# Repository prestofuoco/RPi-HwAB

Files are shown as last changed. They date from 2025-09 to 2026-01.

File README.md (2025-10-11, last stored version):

# raspberry pi 5 hardware acceleration hat+ with xc7a

> **⚠️ work in progress:** this project is currently in the active pcb design and development phase. the hardware is not yet finalized or available. the repository structure, code, and documentation are placeholders for what is planned. stay tuned for updates!

## overview

welcome to the official repository for my raspberry pi 5 hat+ hardware accelerator. this project aims to create a powerful accelerator board featuring a xilinx artix-7 (xc7a) fpga. the goal is to bring high-speed, parallel processing capabilities to the raspberry pi 5, enabling a new generation of projects in fields like real-time signal processing, machine learning, and computer vision.

currently, the focus is on the **pcb design and layout**. the `pcb/` directory contains the most up-to-date work. other sections of this repository, such as `fpga_src` and `examples`, contain planned structures and will be developed once the hardware is stable.

## planned key features

* **xilinx artix-7 fpga:** will utilize the powerful and efficient xc7a series fpga for custom hardware acceleration
* **hat+ compliant:** designed to the latest raspberry pi hat+ specification for seamless integration and configuration
* **high-speed pcie interface:** aims to leverage the raspberry pi 5's pcie capabilities for maximum data throughput
* **on-board peripherals:** the design will include various peripherals which will be noted here
* **open-source design:** the pcb design, verilog/vhdl examples, and host software will be open-source and available in this repository

## hardware and software requirements (provisional)

### hardware

* a raspberry pi 5
* the final version of this xc7a fpga hat+ board
* a reliable power supply for the raspberry pi 5 (5v/5a recommended)

### software (provisional)

* **raspberry pi os:** ubuntu server 20.04+
* **xilinx vivado design suite:** for developing fpga bitstreams
* **kicad:** for viewing and editing the pcb design files

## project status

this project is currently focused on hardware development.

### 1. pcb design

the kicad project files can be found in the `pcb/` directory. this is the primary area of development right now. feedback and contributions for schematics and layout are welcome.

### 2. future steps (post-hardware)

once the pcb is finalized and fabricated, development will shift to:

1. **board bring-up and testing:** verifying all hardware components.
2. **fpga development:** creating example bitstreams (e.g., led blinker, pcie communication).
3. **host-side software:** writing drivers and libraries to communicate with the fpga from the raspberry pi.

## repository structure

```
.
├── bitstreams/       # (planned) pre-compiled fpga bitstream files
├── docs/             # (planned) detailed documentation and datasheets
├── examples/         # (planned) example projects (host-side code)
├── fpga_src/         # (backlog) verilog/vhdl source code for the fpga
│   └── RPi-HwAB-1/   # main vivado project files
│   └── test/         # pinout verification/experimentation
├── pcb/              # (active development) kicad/altium project files
│   └── simulations/  # ltspice simulation files
├── scripts/          # (planned) installation and helper scripts
├── utils/            # (planned) host-side utility programs
└── readme.md         # this file
```

## contact

andre winkel 14 [at] gmail [dot] com

andre [dot] winkel [at] email [dot] ucr [dot] edu

project link: [https://github.com/prestofuoco/rpi-hwab](https://github.com/prestofuoco/rpi-hwab)

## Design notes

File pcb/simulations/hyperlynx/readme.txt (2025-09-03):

*******************************************************************************
** © Copyright 2012 Xilinx, Inc. All rights reserved.
** This file contains confidential and proprietary information of Xilinx, Inc. and 
** is protected under U.S. and international copyright and other intellectual property laws.
*******************************************************************************
**   ____  ____ 
**  /   /\/   / 
** /___/  \  /   Vendor: Xilinx 
** \   \   \/    
**  \   \        readme.txt Version: 2.8
**  /   /        Date Last Modified: 8/28/2017
** /___/   /\    Date Created: 6/28/2012
** \   \  /  \   Associated Filename: artix7_ibis_v2_8.zip
**  \___\/\___\ 
** 
**  Device: Artix-7
**  Revision History: 2.8 Additional Packages added
**                    2.0 Production model release
**                    1.0 Preliminary model release
**
*******************************************************************************
**
**  Disclaimer: 
**
**		This disclaimer is not a license and does not grant any rights to the materials 
**              distributed herewith. Except as otherwise provided in a valid license issued to you 
**              by Xilinx, and to the maximum extent permitted by applicable law: 
**              (1) THESE MATERIALS ARE MADE AVAILABLE "AS IS" AND WITH ALL FAULTS, 
**              AND XILINX HEREBY DISCLAIMS ALL WARRANTIES AND CONDITIONS, EXPRESS, IMPLIED, OR STATUTORY, 
**              INCLUDING BUT NOT LIMITED TO WARRANTIES OF MERCHANTABILITY, NON-INFRINGEMENT, OR 
**              FITNESS FOR ANY PARTICULAR PURPOSE; and (2) Xilinx shall not be liable (whether in contract 
**              or tort, including negligence, or under any other theory of liability) for any loss or damage 
**              of any kind or nature related to, arising under or in connection with these materials, 
**              including for any direct, or any indirect, special, incidental, or consequential loss 
**              or damage (including loss of data, profits, goodwill, or any type of loss or damage suffered 
**              as a result of any action brought by a third party) even if such damage or loss was 
**              reasonably foreseeable or Xilinx had been advised of the possibility of the same.

**  Critical Applications:
**
**		Xilinx products are not designed or intended to be fail-safe, or for use in any application 
**		requiring fail-safe performance, such as life-support or safety devices or systems, 
**		Class III medical devices, nuclear facilities, applications related to the deployment of airbags,
**		or any other applications that could lead to death, personal injury, or severe property or 
**		environmental damage (individually and collectively, "Critical Applications"). Customer assumes 
**		the sole risk and liability of any use of Xilinx products in Critical Applications, subject only 
**		to applicable laws and regulations governing limitations on product liability.

**  THIS COPYRIGHT NOTICE AND DISCLAIMER MUST BE RETAINED AS PART OF THIS FILE AT ALL TIMES.

*******************************************************************************

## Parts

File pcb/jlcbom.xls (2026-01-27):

Comment | topDesignator | bottomDesignator | Footprint | JLCPCB Part #
0.0031% |  |  | Resistor_SMD:R_1206_3216Metric | C154631
2.2K1% |  |  | Resistor_SMD:R_0402_1005Metric | C2076947
4.7uF |  |  | Capacitor_SMD:C_0603_1608Metric | C19666
100K |  |  | Resistor_SMD:R_0402_1005Metric | C481918
INA230AIRGTR |  |  | Package_DFN_QFN:VQFN-16-1EP_3x3mm_P0.5mm_EP1.6x1.6mm | C882784
0.1uF |  |  | Capacitor_SMD:C_0402_1005Metric | C1525
1001% |  |  | Resistor_SMD:R_0402_1005Metric | C844502
LEDGreen |  |  | LED_SMD:LED_0603_1608Metric | C125093
15K1% |  |  | Resistor_SMD:R_0402_1005Metric | C191587
Hirose_FH12-16S |  |  | Connector_FFC-FPC:Hirose_FH12-17S-0.5SH_1x17-1MP_P0.50mm_Horizontal | C596731
10uF |  |  | Capacitor_SMD:C_1206_3216Metric | C13585
1.5uH |  |  | Inductor_SMD:L_Coilcraft_XAL4020-XXX | C3040382
XC7A100T-FGG484 |  |  | library:Xilinx_FGG484 | C410276
10 |  |  | Resistor_SMD:R_0402_1005Metric | C138066
MCP9804T-E/MC |  |  | Package_DFN_QFN:DFN-8-1EP_3x2mm_P0.5mm_EP1.7x1.4mm | C194710
4.7K |  |  | Resistor_SMD:R_0402_1005Metric | C482193
2401% |  |  | Resistor_SMD:R_0402_1005Metric | C843898
MT41K256M16TW-107:PTR |  |  | Package_BGA:Micron_FBGA-96_7.5x13.5mm_Layout9x16_P0.8mm | C253882
1K |  |  | Resistor_SMD:R_0402_1005Metric | C105637
MX25L12835F |  |  | Package_SON:WSON-8-1EP_6x5mm_P1.27mm_EP3.4x4mm | C190862
4.7nF |  |  | Capacitor_SMD:C_0402_1005Metric | C1538
LEDRed |  |  | LED_SMD:LED_0603_1608Metric | C94869
TPSM82903 |  |  | library:TPSM82903SISR | C6290583
120R@100MHz |  |  | Inductor_SMD:L_0603_1608Metric | C85831
22K |  |  | Resistor_SMD:R_0402_1005Metric | C82868
LEDBlue |  |  | LED_SMD:LED_0603_1608Metric | C99290
22uF |  |  | Capacitor_SMD:C_0603_1608Metric | C59461
0.005 |  |  | Resistor_SMD:R_1206_3216Metric | C844909
2.2uF |  |  | Capacitor_SMD:C_0603_1608Metric | C23630
10K1% |  |  | Resistor_SMD:R_0402_1005Metric | C71617
SiT9365AI-2B2-33 |  |  | Oscillator:Oscillator_SMD_SiTime_PQFD-6L_3.2x2.5mm | C831617
3.9K |  |  | Resistor_SMD:R_0402_1005Metric | C131467
330 |  |  | Resistor_SMD:R_0402_1005Metric | C105875
CAT24C256 |  |  | Package_DFN_QFN:DFN-8-1EP_3x2mm_P0.5mm_EP1.7x1.4mm | C233771
GPIO |  |  | Connector_PinSocket_2.54mm:PinSocket_2x20_P2.54mm_Vertical | C2977589

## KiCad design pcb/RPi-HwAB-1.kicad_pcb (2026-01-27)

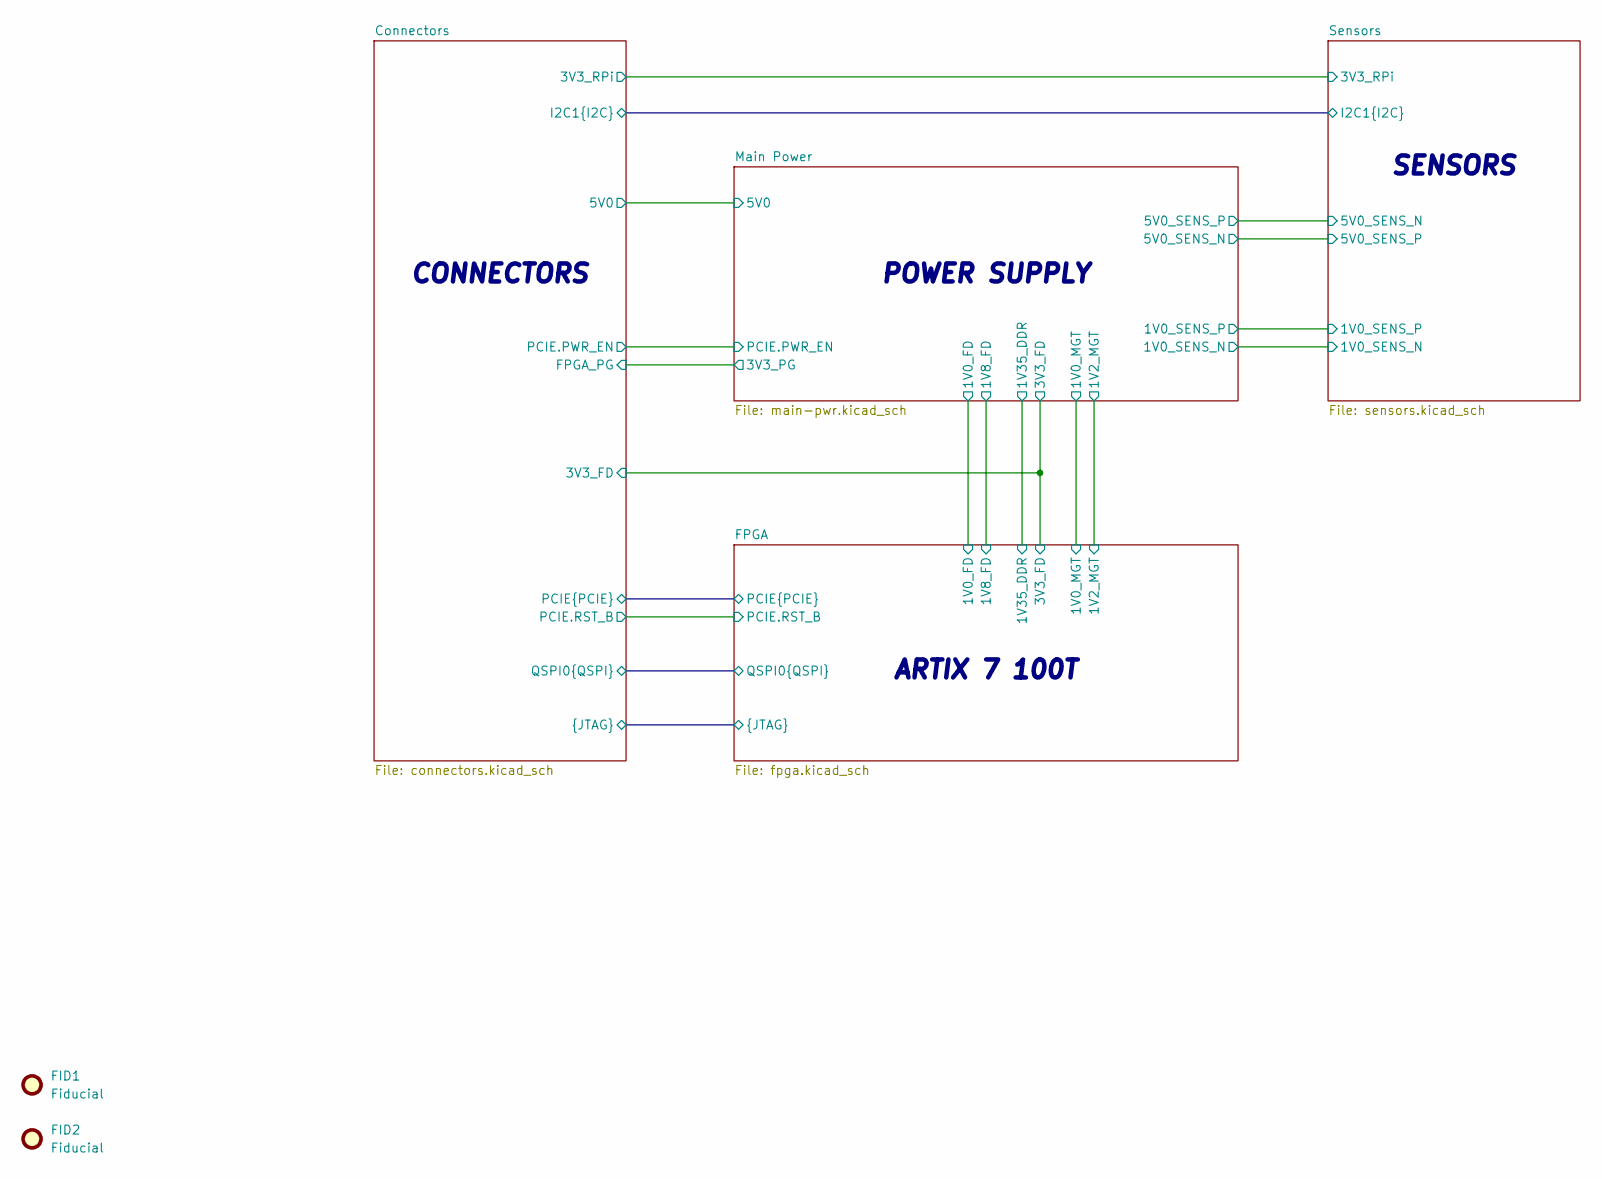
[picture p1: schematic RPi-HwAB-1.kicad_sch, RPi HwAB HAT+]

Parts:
FID1, FID2: Fiducial; Fiducial_1mm_Mask3mm

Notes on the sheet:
ARTIX 7 100T
SENSORS
CONNECTORS
POWER SUPPLY

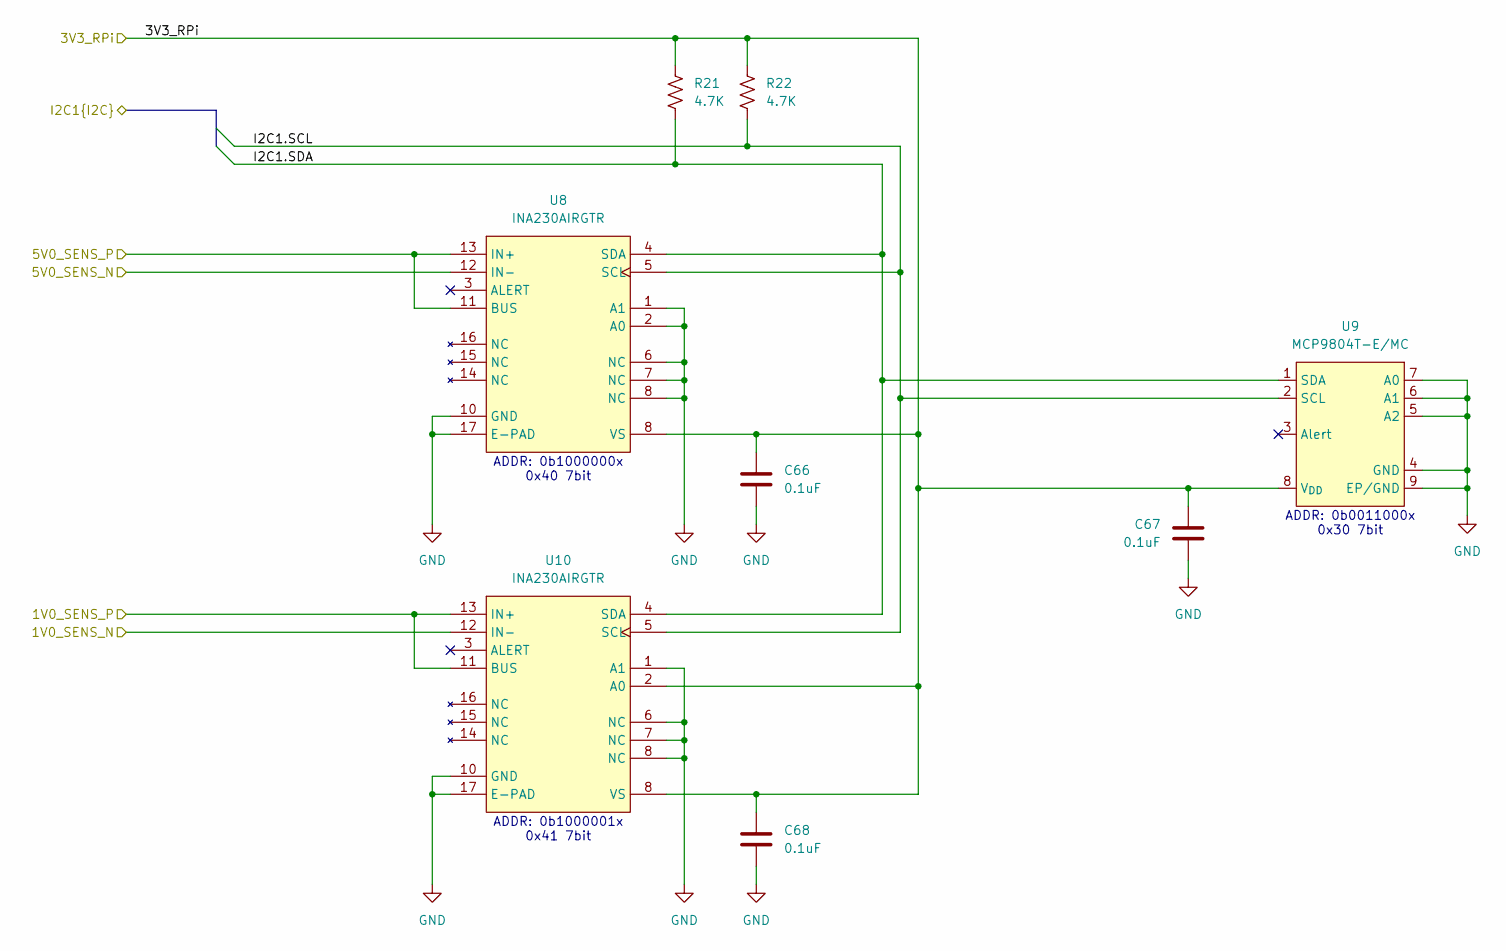
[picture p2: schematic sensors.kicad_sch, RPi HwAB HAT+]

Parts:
C66, C67, C68: 0.1uF; C_0402_1005Metric; Part Description CAP CER 0.1UF 16V X7R 0402
R21, R22: 4.7K; R_0402_1005Metric; Part Description RES 4.7K OHM 1% 1/16W 0402
U8, U10: INA230AIRGTR; VQFN-16-1EP_3x3mm_P0.5mm_EP1.6x1.6mm; Part Description IC CURRENT MONITOR 0.005 16VQFN
U9: MCP9804T-E/MC; DFN-8-1EP_3x2mm_P0.5mm_EP1.7x1.4mm; Part Description SENSOR DIGITAL -40C-125C 8DFN

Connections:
/Connectors/I2C1.SCL: R22.2, U8.5 (SCL), U9.2 (SCL), U10.5 (SCL); also elsewhere on the board
/Connectors/I2C1.SDA: R21.2, U8.4 (SDA), U9.1 (SDA), U10.4 (SDA); also elsewhere on the board
/Main Power/1V0_SENS_N: U10.12 (IN-); also elsewhere on the board
/Main Power/1V0_SENS_P: U10.11 (BUS), U10.13 (IN+); also elsewhere on the board
/Main Power/5V0_SENS_N: U8.11 (BUS), U8.13 (IN+); also elsewhere on the board
/Main Power/5V0_SENS_P: U8.12 (IN-); also elsewhere on the board

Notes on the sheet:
ADDR: 0b0011000x 0x30 7bit
ADDR: 0b1000001x 0x41 7bit
ADDR: 0b1000000x 0x40 7bit

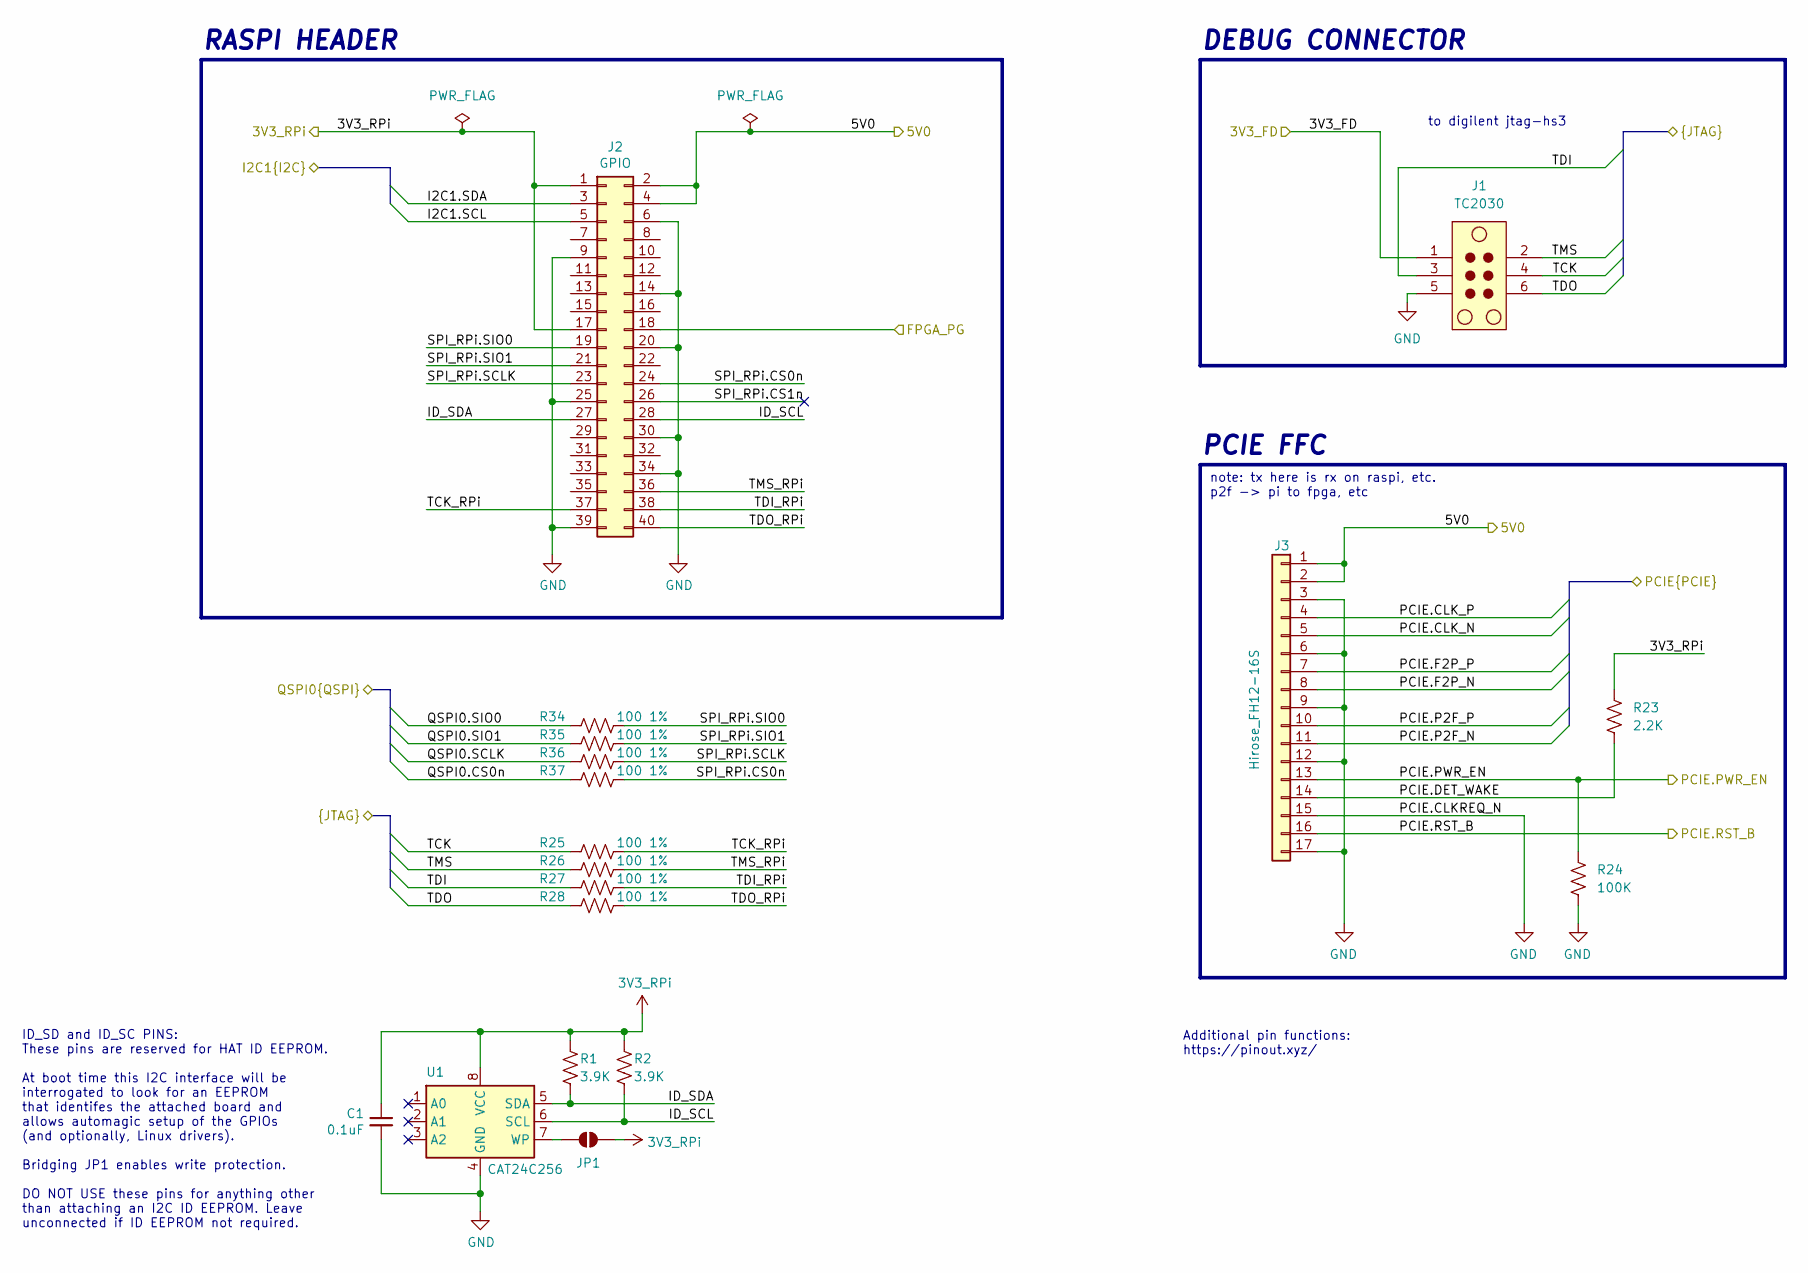
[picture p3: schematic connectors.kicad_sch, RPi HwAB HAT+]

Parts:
C1: 0.1uF; C_0402_1005Metric; Part Description CAP CER 0.1UF 16V X7R 0402
J1: TC2030; Tag-Connect_TC2030-IDC-NL_2x03_P1.27mm_Vertical
J2: GPIO; PinSocket_2x20_P2.54mm_Vertical; Part Description CONN RCPT 40POS 0.1 GOLD PCB
J3: Hirose_FH12-16S; Hirose_FH12-17S-0.5SH_1x17-1MP_P0.50mm_Horizontal; Part Description CONN FFC FPC BOTTOM 16POS 1MM RA
JP1: ID_WP; SolderJumper-2_P1.3mm_Open_Pad1.0x1.5mm
R1, R2: 3.9K; R_0402_1005Metric; Part Description RES 3.9K OHM 1% 1/16W 0402
R23: 2.2K; R_0402_1005Metric; Part Description RES 2.2K OHM 1% 1/16W 0402
R24: 100K; R_0402_1005Metric; Part Description RES 100K OHM 1% 1/16W 0402
R25, R26, R27, R28, R34, R35, R36, R37: 100 1%; R_0402_1005Metric; Part Description RES SMD 100 OHM 1% 1/5W 0402
U1: CAT24C256; DFN-8-1EP_3x2mm_P0.5mm_EP1.7x1.4mm; Part Description IC EEPROM 256KBIT I2C 1MHZ 8UDFN

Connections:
/Connectors/3V3_FD: J1.1; also elsewhere on the board
/Connectors/5V0: J2.2, J2.4, J3.1, J3.2; also elsewhere on the board
/Connectors/I2C1.SCL: J2.5; also elsewhere on the board
/Connectors/I2C1.SDA: J2.3; also elsewhere on the board
/Connectors/ID_SCL: J2.28, R2.2, U1.6 (SCL)
/Connectors/ID_SDA: J2.27, R1.2, U1.5 (SDA)
/Connectors/PCIE.CLK_N: J3.5; also elsewhere on the board
/Connectors/PCIE.CLK_P: J3.4; also elsewhere on the board
/Connectors/PCIE.DET_WAKE: J3.14, R23.2
/Connectors/PCIE.F2P_N: J3.8; also elsewhere on the board
/Connectors/PCIE.F2P_P: J3.7; also elsewhere on the board
/Connectors/PCIE.P2F_N: J3.11; also elsewhere on the board
/Connectors/PCIE.P2F_P: J3.10; also elsewhere on the board
/Connectors/PCIE.PWR_EN: J3.13, R24.2; also elsewhere on the board
/Connectors/PCIE.RST_B: J3.16; also elsewhere on the board
/Connectors/QSPI0.CS0n: R37.1; also elsewhere on the board
/Connectors/QSPI0.SCLK: R36.1; also elsewhere on the board
/Connectors/QSPI0.SIO0: R34.1; also elsewhere on the board
/Connectors/QSPI0.SIO1: R35.1; also elsewhere on the board
/Connectors/SPI_RPi.CS0n: J2.24, R37.2
/Connectors/SPI_RPi.CS1n: J2.26
/Connectors/SPI_RPi.SCLK: J2.23, R36.2
/Connectors/SPI_RPi.SIO0: J2.19, R34.2
/Connectors/SPI_RPi.SIO1: J2.21, R35.2
/Connectors/TCK: J1.4, R25.1; also elsewhere on the board
/Connectors/TCK_RPi: J2.37, R25.2
/Connectors/TDI: J1.3, R27.1; also elsewhere on the board
/Connectors/TDI_RPi: J2.38, R27.2
/Connectors/TDO: J1.6, R28.1; also elsewhere on the board
/Connectors/TDO_RPi: J2.40, R28.2
/Connectors/TMS: J1.2, R26.1; also elsewhere on the board
/Connectors/TMS_RPi: J2.36, R26.2
/Main Power/3V3_PG: J2.18; also elsewhere on the board
unnamed: JP1.1 (A), U1.7 (WP)

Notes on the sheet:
PCIE FFC
note: tx here is rx on raspi, etc. p2f -> pi to fpga, etc
Additional pin functions: https://pinout.xyz/
RASPI HEADER
ID_SD and ID_SC PINS: These pins are reserved for HAT ID EEPROM. At boot time this I2C interface will be interrogated to look for an EEPROM that identifes the attached board and allows automagic setup of the GPIOs (and optionally, Linux drivers). Bridging JP1 enables write protection. DO NOT USE th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
DEBUG CONNECTOR
to digilent jtag-hs3

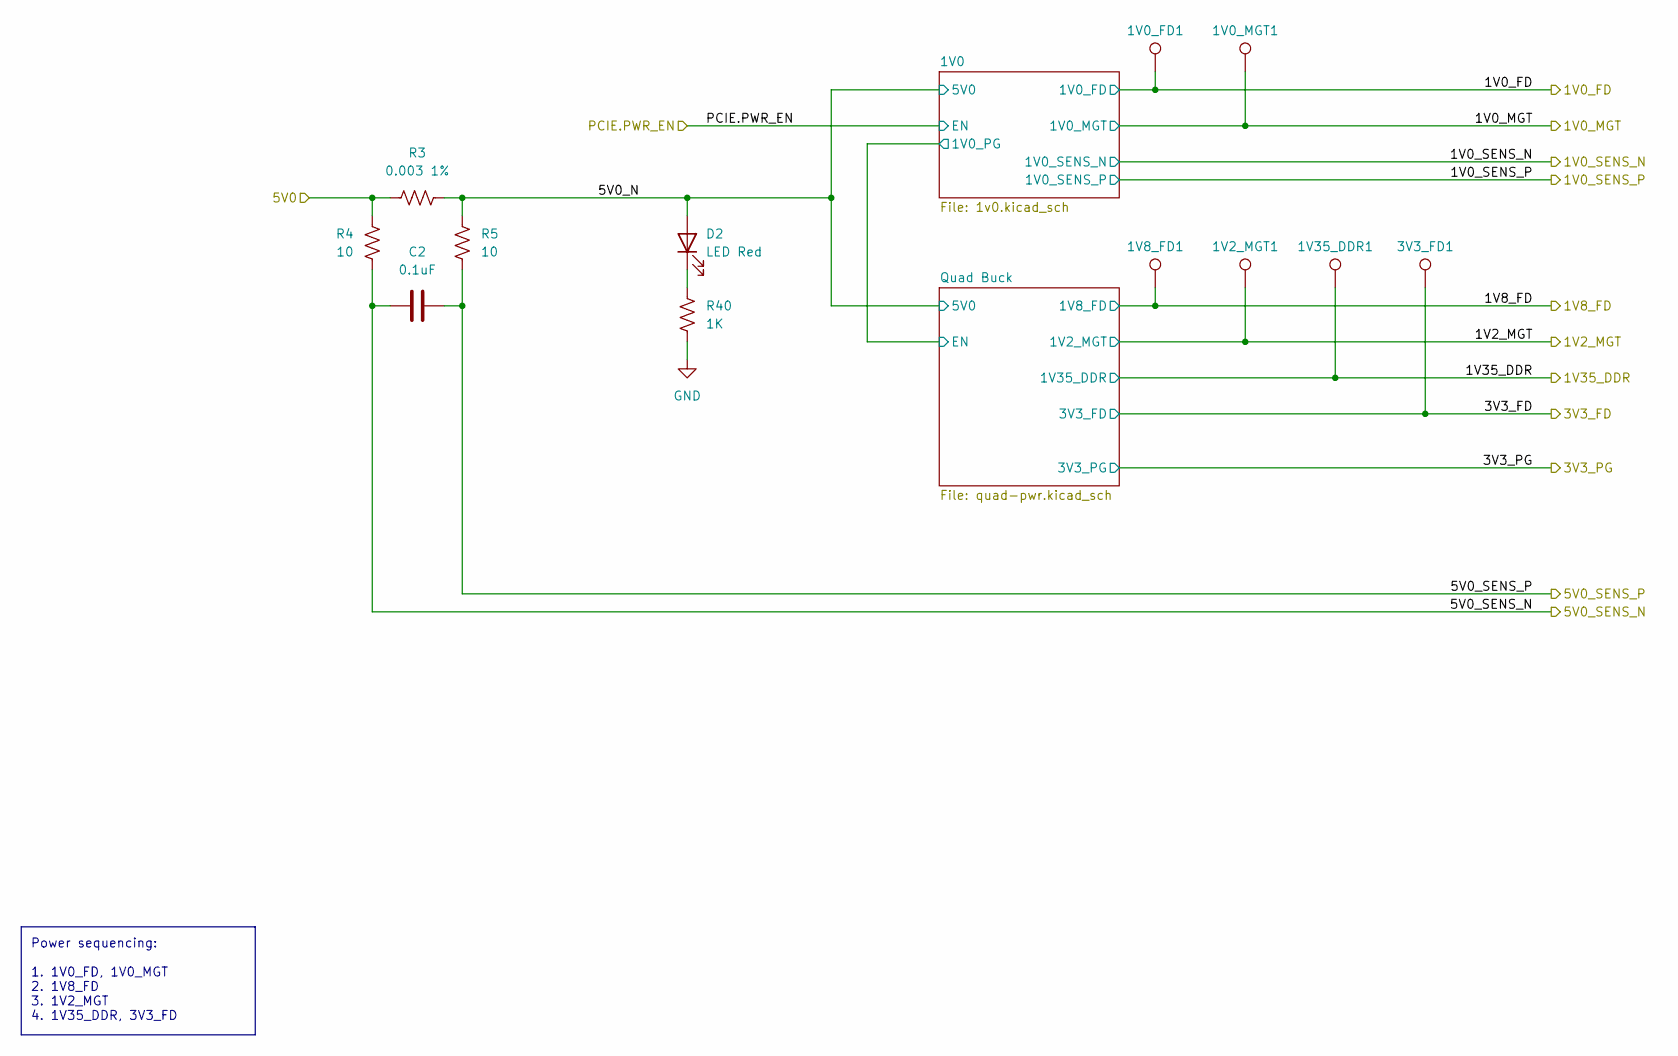
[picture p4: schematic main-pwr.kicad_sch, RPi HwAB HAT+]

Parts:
1V0_FD1, 1V0_MGT1, 1V2_MGT1, 1V8_FD1, 1V35_DDR1, 3V3_FD1: TestPoint; TestPoint_Pad_D1.0mm
C2: 0.1uF; C_0402_1005Metric; Part Description CAP CER 0.1UF 16V X7R 0402
D2: LED Red; LED_0603_1608Metric; Part Description LED RED CLEAR CHIP SMD
R3: 0.003 1%; R_1206_3216Metric; Part Description WSKW0612 .003 1% EA E3
R4, R5: 10; R_0402_1005Metric; Part Description RES 10 OHM 1% 1/16W 0402
R40: 1K; R_0402_1005Metric; Part Description RES 1K OHM 5% 1/16W 0402

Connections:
/Connectors/5V0: R3.1, R4.2; also elsewhere on the board
/Main Power/5V0_N: D2.2 (A), R3.2, R5.2; also elsewhere on the board
/Main Power/5V0_SENS_N: C2.1, R4.1; also elsewhere on the board
/Main Power/5V0_SENS_P: C2.2, R5.1; also elsewhere on the board
unnamed: D2.1 (K), R40.1

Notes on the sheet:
Power sequencing: 1. 1V0_FD, 1V0_MGT 2. 1V8_FD 3. 1V2_MGT 4. 1V35_DDR, 3V3_FD

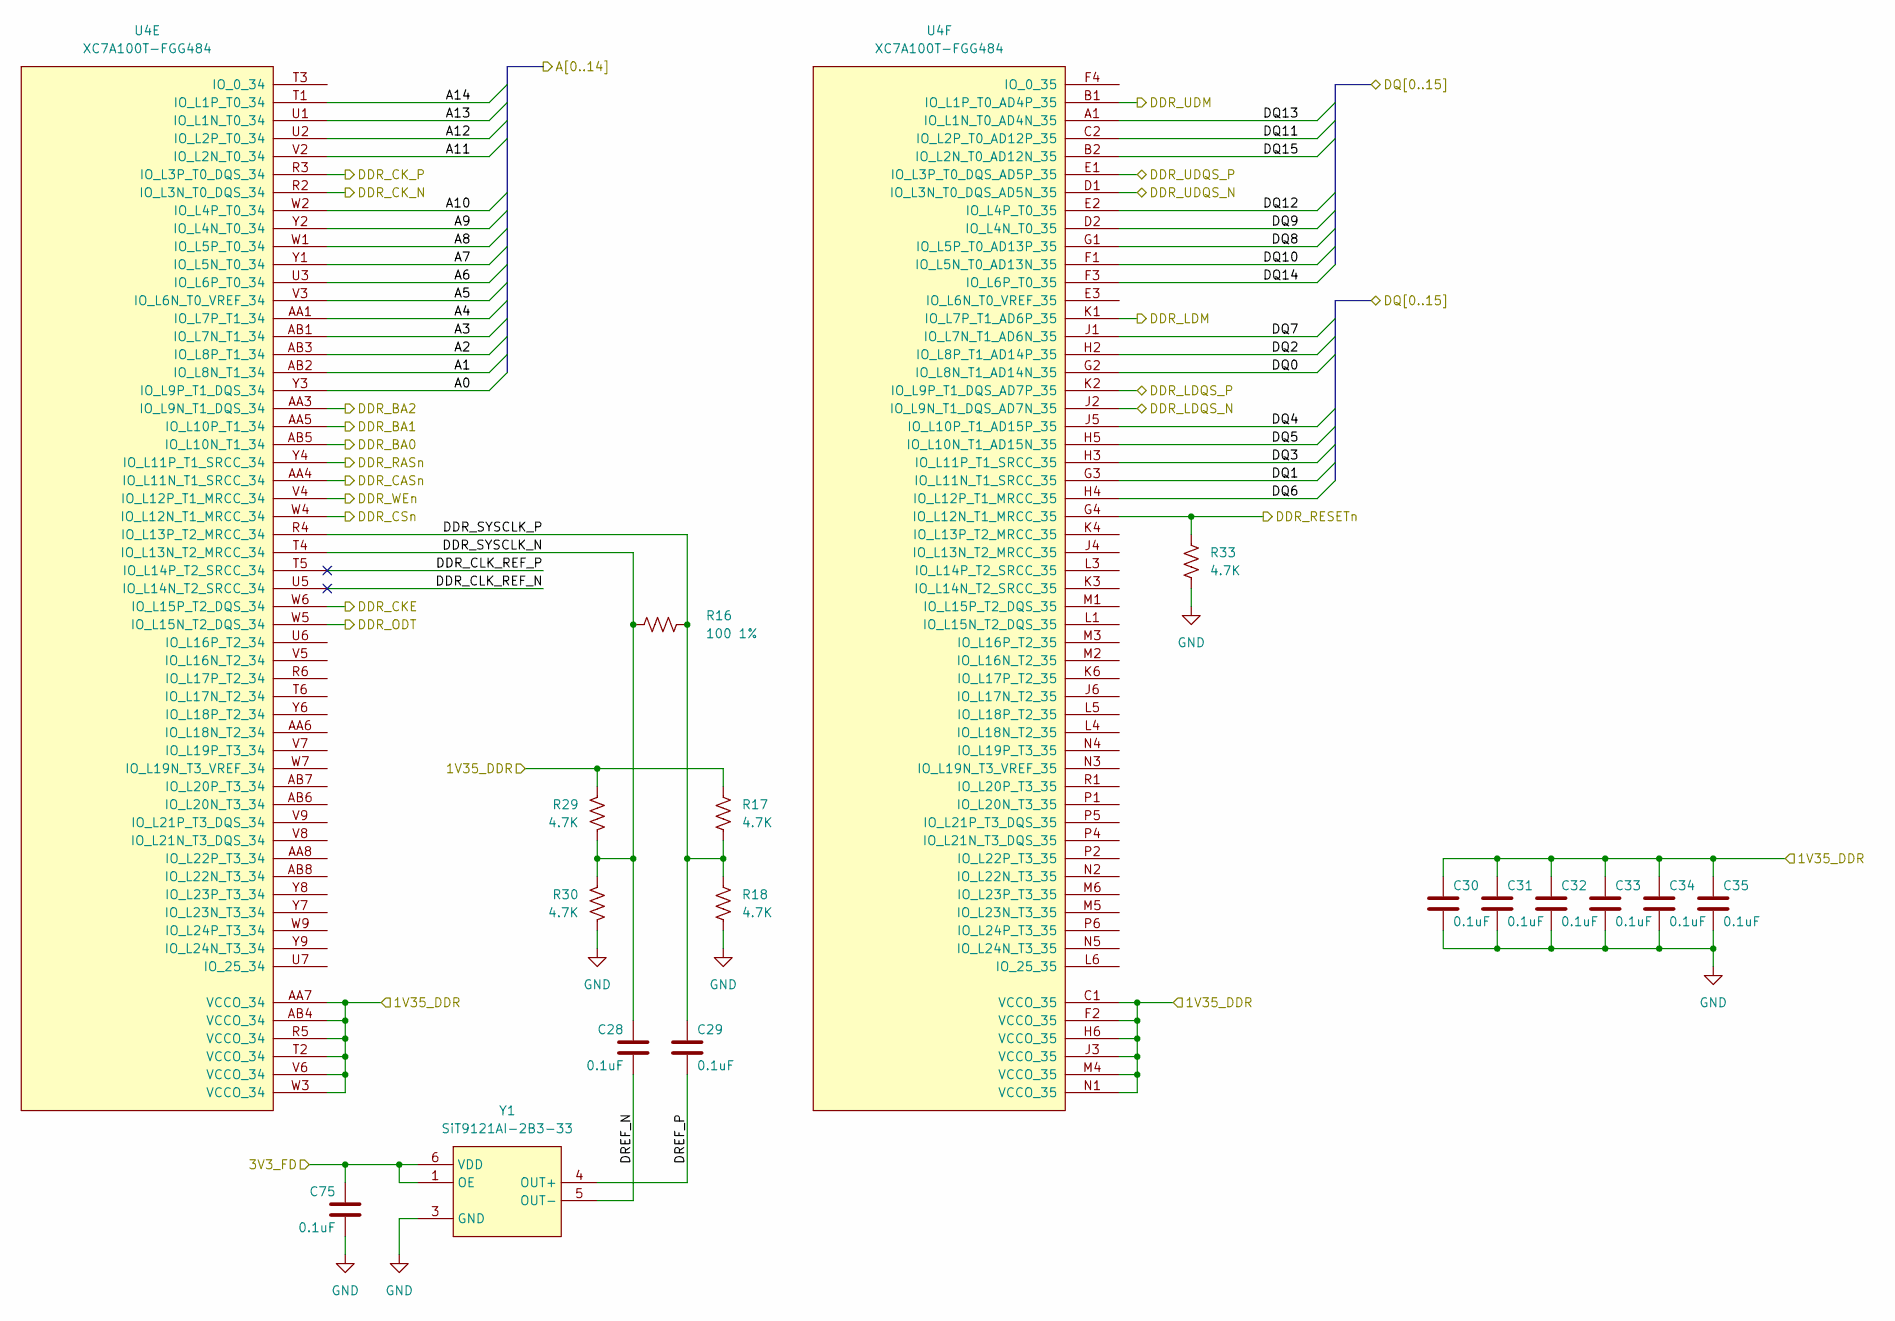
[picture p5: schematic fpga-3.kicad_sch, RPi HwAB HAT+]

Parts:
C28, C29, C30, C31, C32, C33, C34, C35, C75: 0.1uF; C_0402_1005Metric; Part Description CAP CER 0.1UF 16V X7R 0402
R16: 100 1%; R_0402_1005Metric; Part Description RES SMD 100 OHM 1% 1/5W 0402
R17, R18, R29, R30, R33: 4.7K; R_0402_1005Metric; Part Description RES 4.7K OHM 1% 1/16W 0402
U4: XC7A100T-FGG484; Xilinx_FGG484; Part Description IC FPGA 285 I/O 484FBGA
Y1: SiT9121AI-2B3-33; Oscillator_SMD_SiTime_PQFD-6L_3.2x2.5mm; Part Description MEMS OSC XO 156.2500MHZ LVDS SMD

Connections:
/Connectors/3V3_FD: C75.2, Y1.1 (OE), Y1.6 (VDD); also elsewhere on the board
/FPGA/FPGA 34, 35/A0: U4.Y3 (IO_L9P_T1_DQS_34); also elsewhere on the board
/FPGA/FPGA 34, 35/A1: U4.AB2 (IO_L8N_T1_34); also elsewhere on the board
/FPGA/FPGA 34, 35/A2: U4.AB3 (IO_L8P_T1_34); also elsewhere on the board
/FPGA/FPGA 34, 35/A3: U4.AB1 (IO_L7N_T1_34); also elsewhere on the board
/FPGA/FPGA 34, 35/A4: U4.AA1 (IO_L7P_T1_34); also elsewhere on the board
/FPGA/FPGA 34, 35/A5: U4.V3 (IO_L6N_T0_VREF_34); also elsewhere on the board
/FPGA/FPGA 34, 35/A6: U4.U3 (IO_L6P_T0_34); also elsewhere on the board
/FPGA/FPGA 34, 35/A7: U4.Y1 (IO_L5N_T0_34); also elsewhere on the board
/FPGA/FPGA 34, 35/A8: U4.W1 (IO_L5P_T0_34); also elsewhere on the board
/FPGA/FPGA 34, 35/A9: U4.Y2 (IO_L4N_T0_34); also elsewhere on the board
/FPGA/FPGA 34, 35/A10: U4.W2 (IO_L4P_T0_34); also elsewhere on the board
/FPGA/FPGA 34, 35/A11: U4.V2 (IO_L2N_T0_34); also elsewhere on the board
/FPGA/FPGA 34, 35/A12: U4.U2 (IO_L2P_T0_34); also elsewhere on the board
/FPGA/FPGA 34, 35/A13: U4.U1 (IO_L1N_T0_34); also elsewhere on the board
/FPGA/FPGA 34, 35/A14: U4.T1 (IO_L1P_T0_34); also elsewhere on the board
/FPGA/FPGA 34, 35/DDR_BA0: U4.AB5 (IO_L10N_T1_34); also elsewhere on the board
/FPGA/FPGA 34, 35/DDR_BA1: U4.AA5 (IO_L10P_T1_34); also elsewhere on the board
/FPGA/FPGA 34, 35/DDR_BA2: U4.AA3 (IO_L9N_T1_DQS_34); also elsewhere on the board
/FPGA/FPGA 34, 35/DDR_CASn: U4.AA4 (IO_L11N_T1_SRCC_34); also elsewhere on the board
/FPGA/FPGA 34, 35/DDR_CKE: U4.W6 (IO_L15P_T2_DQS_34); also elsewhere on the board
/FPGA/FPGA 34, 35/DDR_CK_N: U4.R2 (IO_L3N_T0_DQS_34); also elsewhere on the board
/FPGA/FPGA 34, 35/DDR_CK_P: U4.R3 (IO_L3P_T0_DQS_34); also elsewhere on the board
/FPGA/FPGA 34, 35/DDR_CLK_REF_N: U4.U5 (IO_L14N_T2_SRCC_34)
/FPGA/FPGA 34, 35/DDR_CLK_REF_P: U4.T5 (IO_L14P_T2_SRCC_34)
/FPGA/FPGA 34, 35/DDR_CSn: U4.W4 (IO_L12N_T1_MRCC_34); also elsewhere on the board
/FPGA/FPGA 34, 35/DDR_LDM: U4.K1 (IO_L7P_T1_AD6P_35); also elsewhere on the board
/FPGA/FPGA 34, 35/DDR_LDQS_N: U4.J2 (IO_L9N_T1_DQS_AD7N_35); also elsewhere on the board
/FPGA/FPGA 34, 35/DDR_LDQS_P: U4.K2 (IO_L9P_T1_DQS_AD7P_35); also elsewhere on the board
/FPGA/FPGA 34, 35/DDR_ODT: U4.W5 (IO_L15N_T2_DQS_34); also elsewhere on the board
/FPGA/FPGA 34, 35/DDR_RASn: U4.Y4 (IO_L11P_T1_SRCC_34); also elsewhere on the board
/FPGA/FPGA 34, 35/DDR_RESETn: R33.1, U4.G4 (IO_L12N_T1_MRCC_35); also elsewhere on the board
/FPGA/FPGA 34, 35/DDR_SYSCLK_N: C28.1, R16.1, R29.2, R30.1, U4.T4 (IO_L13N_T2_MRCC_34)
/FPGA/FPGA 34, 35/DDR_SYSCLK_P: C29.1, R16.2, R17.2, R18.1, U4.R4 (IO_L13P_T2_MRCC_34)
/FPGA/FPGA 34, 35/DDR_UDM: U4.B1 (IO_L1P_T0_AD4P_35); also elsewhere on the board
/FPGA/FPGA 34, 35/DDR_UDQS_N: U4.D1 (IO_L3N_T0_DQS_AD5N_35); also elsewhere on the board
/FPGA/FPGA 34, 35/DDR_UDQS_P: U4.E1 (IO_L3P_T0_DQS_AD5P_35); also elsewhere on the board
/FPGA/FPGA 34, 35/DDR_WEn: U4.V4 (IO_L12P_T1_MRCC_34); also elsewhere on the board
/FPGA/FPGA 34, 35/DQ0: U4.G2 (IO_L8N_T1_AD14N_35); also elsewhere on the board
/FPGA/FPGA 34, 35/DQ1: U4.G3 (IO_L11N_T1_SRCC_35); also elsewhere on the board
/FPGA/FPGA 34, 35/DQ2: U4.H2 (IO_L8P_T1_AD14P_35); also elsewhere on the board
/FPGA/FPGA 34, 35/DQ3: U4.H3 (IO_L11P_T1_SRCC_35); also elsewhere on the board
/FPGA/FPGA 34, 35/DQ4: U4.J5 (IO_L10P_T1_AD15P_35); also elsewhere on the board
/FPGA/FPGA 34, 35/DQ5: U4.H5 (IO_L10N_T1_AD15N_35); also elsewhere on the board
/FPGA/FPGA 34, 35/DQ6: U4.H4 (IO_L12P_T1_MRCC_35); also elsewhere on the board
/FPGA/FPGA 34, 35/DQ7: U4.J1 (IO_L7N_T1_AD6N_35); also elsewhere on the board
/FPGA/FPGA 34, 35/DQ8: U4.G1 (IO_L5P_T0_AD13P_35); also elsewhere on the board
/FPGA/FPGA 34, 35/DQ9: U4.D2 (IO_L4N_T0_35); also elsewhere on the board
/FPGA/FPGA 34, 35/DQ10: U4.F1 (IO_L5N_T0_AD13N_35); also elsewhere on the board
/FPGA/FPGA 34, 35/DQ11: U4.C2 (IO_L2P_T0_AD12P_35); also elsewhere on the board
/FPGA/FPGA 34, 35/DQ12: U4.E2 (IO_L4P_T0_35); also elsewhere on the board
/FPGA/FPGA 34, 35/DQ13: U4.A1 (IO_L1N_T0_AD4N_35); also elsewhere on the board
/FPGA/FPGA 34, 35/DQ14: U4.F3 (IO_L6P_T0_35); also elsewhere on the board
/FPGA/FPGA 34, 35/DQ15: U4.B2 (IO_L2N_T0_AD12N_35); also elsewhere on the board
/FPGA/FPGA 34, 35/DREF_N: C28.2, Y1.5 (OUT-)
/FPGA/FPGA 34, 35/DREF_P: C29.2, Y1.4 (OUT+)
/Main Power/1V35_DDR: C30.2, C31.2, C32.2, C33.2, C34.2, C35.2, R17.1, R29.1, U4.AA7 (VCCO_34), U4.AB4 (VCCO_34), U4.C1 (VCCO_35), U4.F2 (VCCO_35), U4.H6 (VCCO_35), U4.J3 (VCCO_35), U4.M4 (VCCO_35), U4.N1 (VCCO_35), U4.R5 (VCCO_34), U4.T2 (VCCO_34), U4.V6 (VCCO_34), U4.W3 (VCCO_34); also elsewhere on the board

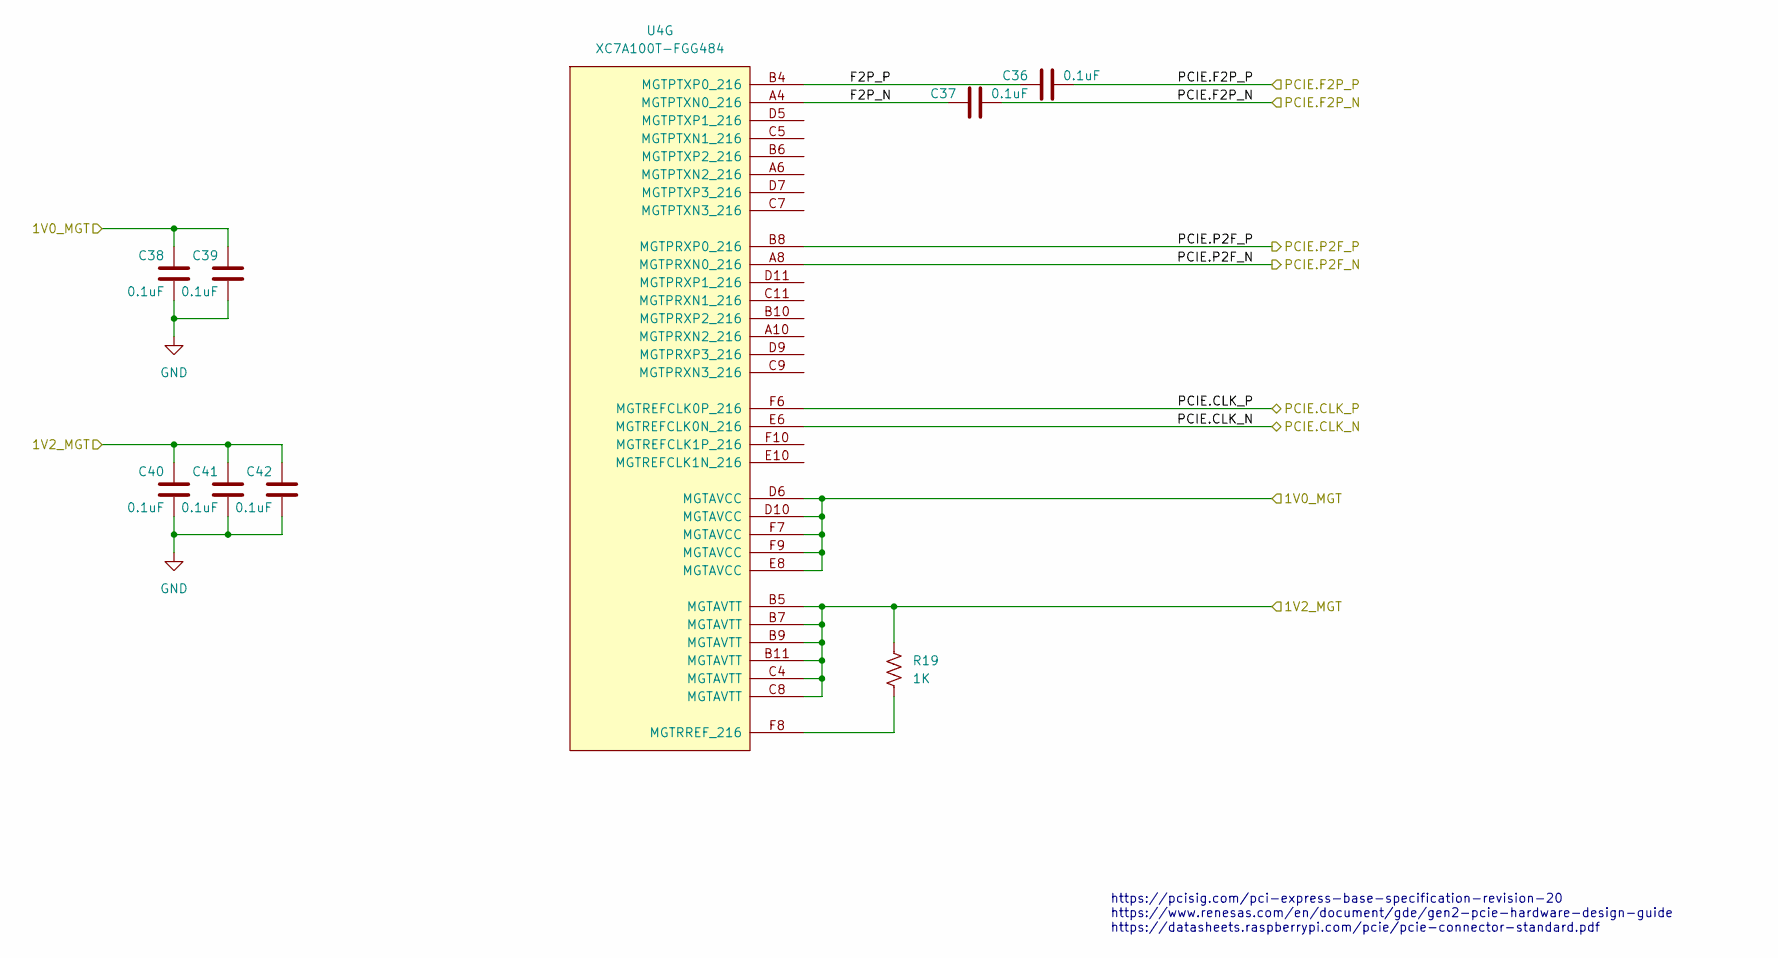
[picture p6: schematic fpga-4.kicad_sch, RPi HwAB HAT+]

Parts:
C36, C37, C38, C39, C40, C41, C42: 0.1uF; C_0402_1005Metric; Part Description CAP CER 0.1UF 16V X7R 0402
R19: 1K; R_0402_1005Metric; Part Description RES 1K OHM 5% 1/16W 0402
U4: XC7A100T-FGG484; Xilinx_FGG484; Part Description IC FPGA 285 I/O 484FBGA

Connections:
/Connectors/PCIE.CLK_N: U4.F6 (MGTREFCLK0P_216); also elsewhere on the board
/Connectors/PCIE.CLK_P: U4.E6 (MGTREFCLK0N_216); also elsewhere on the board
/Connectors/PCIE.F2P_N: C36.2; also elsewhere on the board
/Connectors/PCIE.F2P_P: C37.2; also elsewhere on the board
/Connectors/PCIE.P2F_N: U4.B8 (MGTPRXP0_216); also elsewhere on the board
/Connectors/PCIE.P2F_P: U4.A8 (MGTPRXN0_216); also elsewhere on the board
/FPGA/FPGA 216/F2P_N: C37.1, U4.A4 (MGTPTXN0_216)
/FPGA/FPGA 216/F2P_P: C36.1, U4.B4 (MGTPTXP0_216)
/Main Power/1V0_MGT: C38.2, C39.2, U4.D6 (MGTAVCC), U4.D10 (MGTAVCC), U4.E8 (MGTAVCC), U4.F7 (MGTAVCC), U4.F9 (MGTAVCC); also elsewhere on the board
/Main Power/1V2_MGT: C40.2, C41.2, C42.2, R19.2, U4.B5 (MGTAVTT), U4.B7 (MGTAVTT), U4.B9 (MGTAVTT), U4.B11 (MGTAVTT), U4.C4 (MGTAVTT), U4.C8 (MGTAVTT); also elsewhere on the board
unnamed: R19.1, U4.F8 (MGTRREF_216)

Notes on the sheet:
https://pcisig.com/pci-express-base-specification-revision-20 https://www.renesas.com/en/document/gde/gen2-pcie-hardware-design-guide https://datasheets.raspberrypi.com/pcie/pcie-connector-standard.pdf

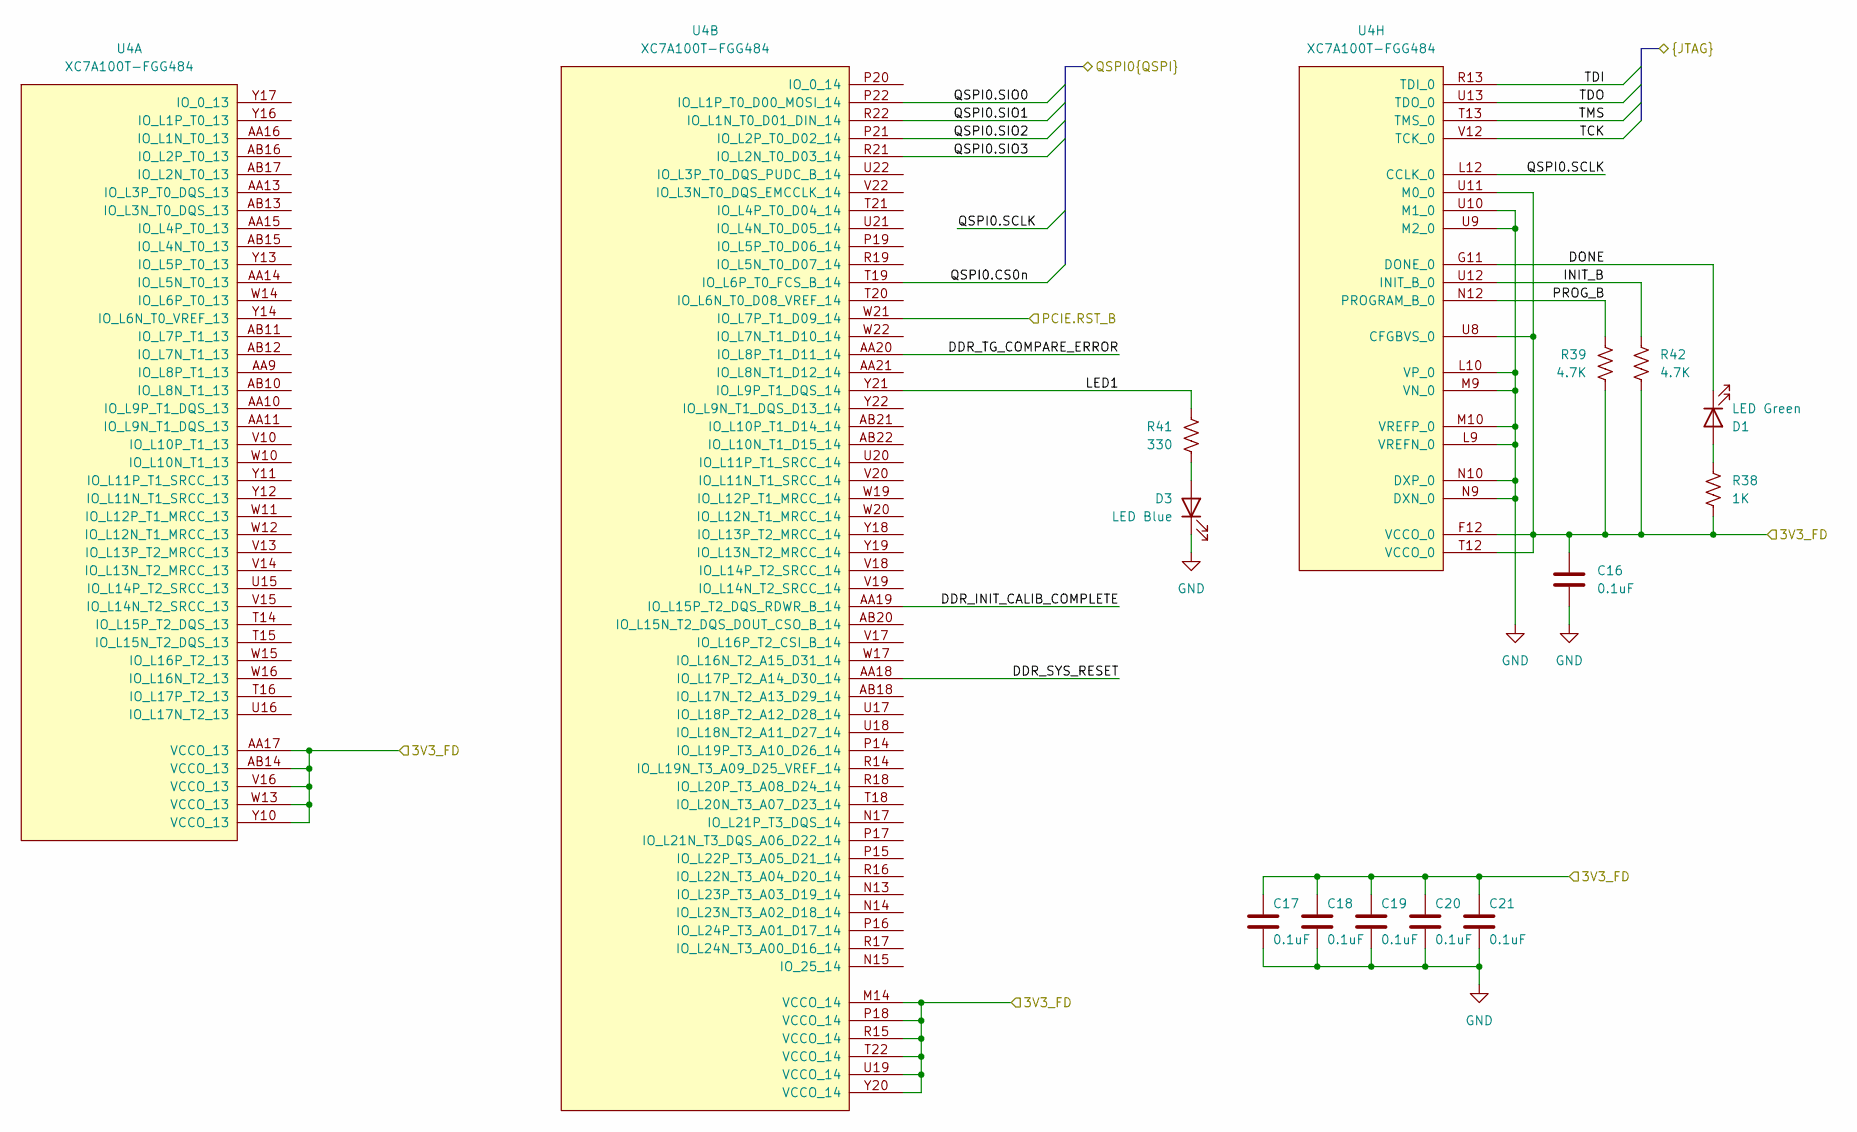
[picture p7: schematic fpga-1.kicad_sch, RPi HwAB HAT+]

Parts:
C16, C17, C18, C19, C20, C21: 0.1uF; C_0402_1005Metric; Part Description CAP CER 0.1UF 16V X7R 0402
D1: LED Green; LED_0603_1608Metric; Part Description LED GREEN CLEAR CHIP SMD
D3: LED Blue; LED_0603_1608Metric; Part Description LED BLUE CLEAR CHIP SMD
R38: 1K; R_0402_1005Metric; Part Description RES 1K OHM 5% 1/16W 0402
R39, R42: 4.7K; R_0402_1005Metric; Part Description RES 4.7K OHM 1% 1/16W 0402
R41: 330; R_0402_1005Metric; Part Description RES 330 OHM 1% 1/16W 0402
U4: XC7A100T-FGG484; Xilinx_FGG484; Part Description IC FPGA 285 I/O 484FBGA

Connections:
/Connectors/3V3_FD: C16.2, C17.2, C18.2, C19.2, C20.2, C21.2, R38.2, R39.2, R42.2, U4.AA17 (VCCO_13), U4.AB14 (VCCO_13), U4.F12 (VCCO_0), U4.M14 (VCCO_14), U4.P18 (VCCO_14), U4.R15 (VCCO_14), U4.T12 (VCCO_0), U4.T22 (VCCO_14), U4.U8 (CFGBVS_0), U4.U11 (M0_0), U4.U19 (VCCO_14), U4.V16 (VCCO_13), U4.W13 (VCCO_13), U4.Y10 (VCCO_13), U4.Y20 (VCCO_14); also elsewhere on the board
/Connectors/PCIE.RST_B: U4.W21 (IO_L7P_T1_D09_14); also elsewhere on the board
/Connectors/QSPI0.CS0n: U4.T19 (IO_L6P_T0_FCS_B_14); also elsewhere on the board
/Connectors/QSPI0.SCLK: U4.L12 (CCLK_0); also elsewhere on the board
/Connectors/QSPI0.SIO0: U4.P22 (IO_L1P_T0_D00_MOSI_14); also elsewhere on the board
/Connectors/QSPI0.SIO1: U4.R22 (IO_L1N_T0_D01_DIN_14); also elsewhere on the board
/Connectors/QSPI0.SIO2: U4.P21 (IO_L2P_T0_D02_14); also elsewhere on the board
/Connectors/QSPI0.SIO3: U4.R21 (IO_L2N_T0_D03_14); also elsewhere on the board
/Connectors/TCK: U4.V12 (TCK_0); also elsewhere on the board
/Connectors/TDI: U4.R13 (TDI_0); also elsewhere on the board
/Connectors/TDO: U4.U13 (TDO_0); also elsewhere on the board
/Connectors/TMS: U4.T13 (TMS_0); also elsewhere on the board
/FPGA/FPGA 0, 13, 14/DDR_INIT_CALIB_COMPLETE: U4.AA19 (IO_L15P_T2_DQS_RDWR_B_14)
/FPGA/FPGA 0, 13, 14/DDR_SYS_RESET: U4.AA18 (IO_L17P_T2_A14_D30_14)
/FPGA/FPGA 0, 13, 14/DDR_TG_COMPARE_ERROR: U4.AA20 (IO_L8P_T1_D11_14)
/FPGA/FPGA 0, 13, 14/DONE: D1.1 (K), U4.G11 (DONE_0)
/FPGA/FPGA 0, 13, 14/INIT_B: R42.1, U4.U12 (INIT_B_0)
/FPGA/FPGA 0, 13, 14/LED1: R41.1, U4.Y21 (IO_L9P_T1_DQS_14)
/FPGA/FPGA 0, 13, 14/PROG_B: R39.1, U4.N12 (PROGRAM_B_0)
unnamed: D1.2 (A), R38.1
unnamed: D3.2 (A), R41.2

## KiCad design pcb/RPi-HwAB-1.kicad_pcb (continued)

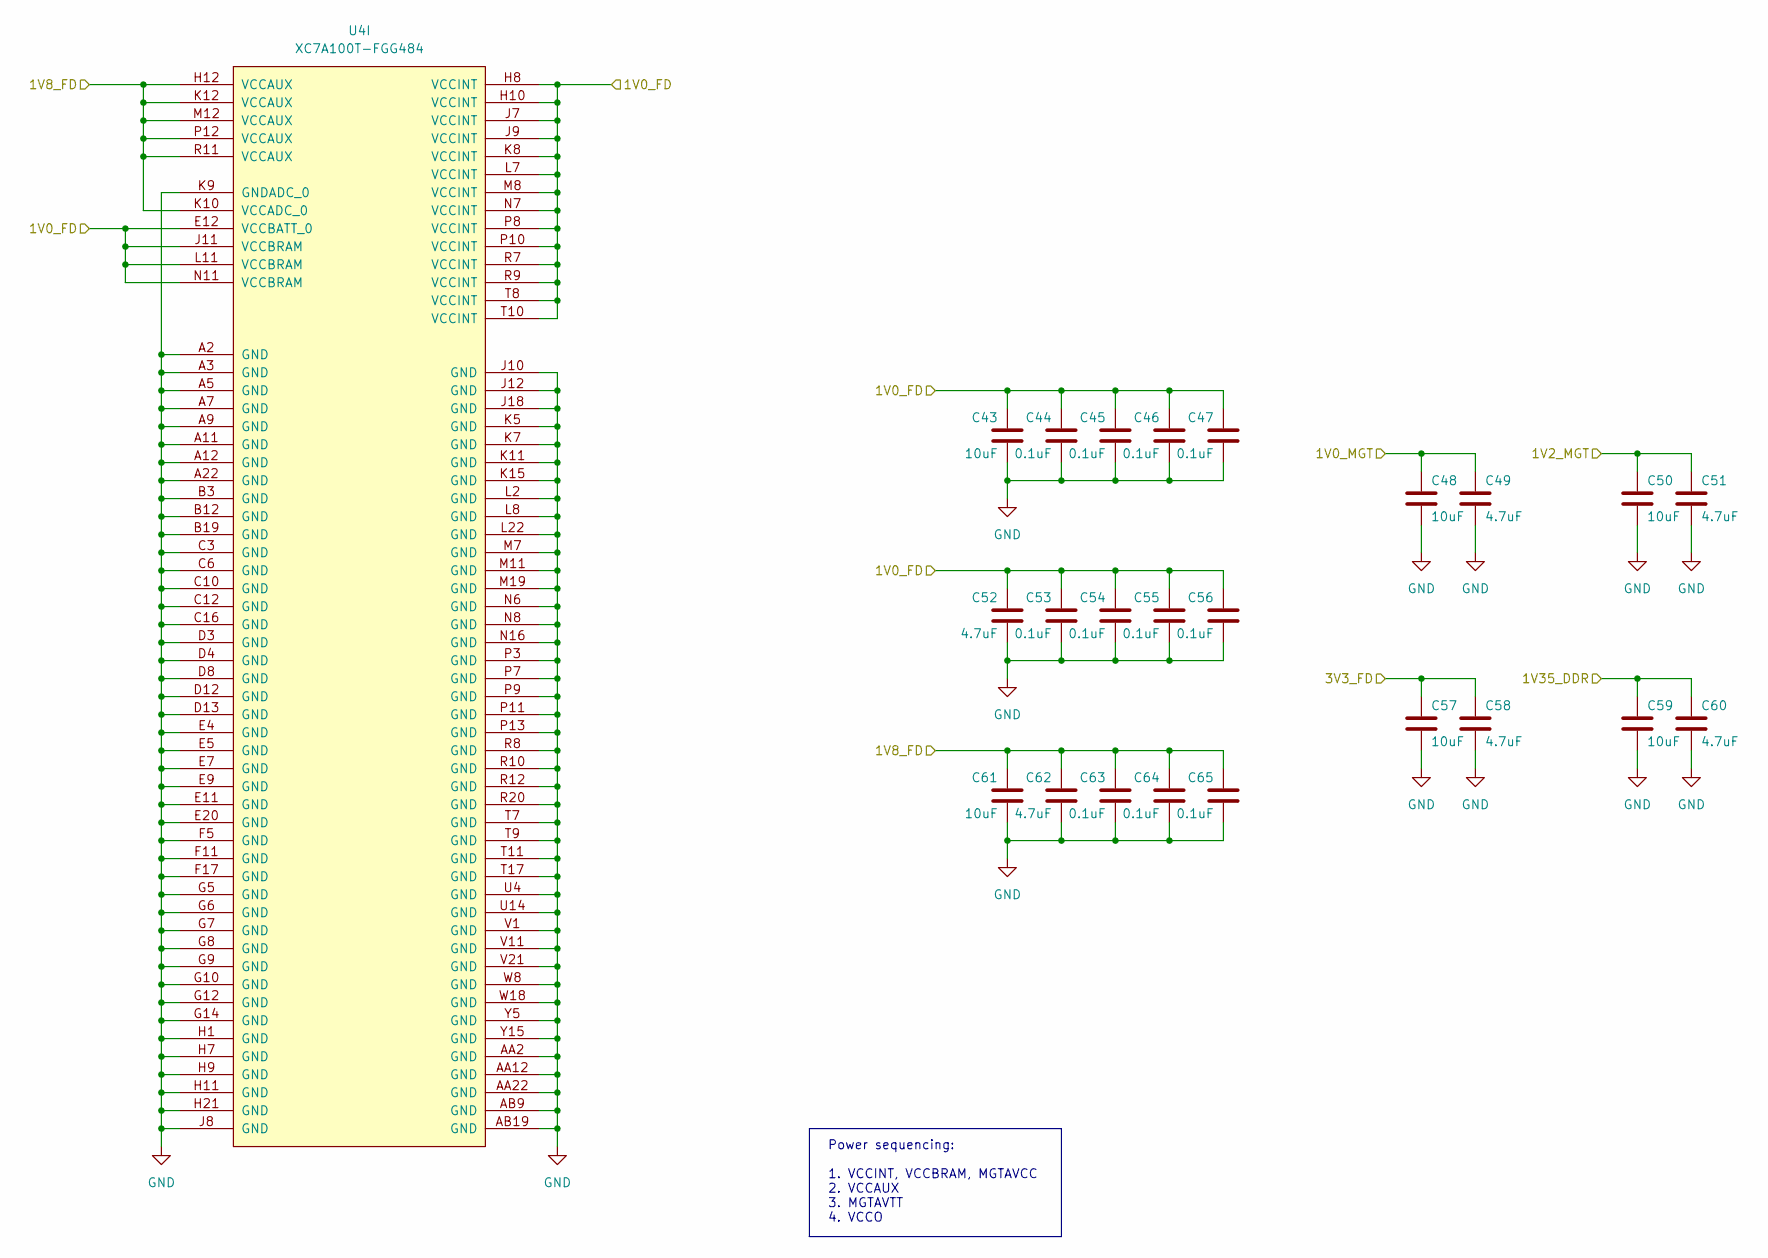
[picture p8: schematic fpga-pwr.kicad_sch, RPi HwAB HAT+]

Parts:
C43, C48, C50, C57, C59, C61: 10uF; C_1206_3216Metric; Part Description CAP TANT 10UF 20% 10V 1206
C44, C45, C46, C47, C53, C54, C55, C56, C63, C64, C65: 0.1uF; C_0402_1005Metric; Part Description CAP CER 0.1UF 16V X7R 0402
C49, C51, C52, C58, C60, C62: 4.7uF; C_0603_1608Metric; Part Description CAP CER 4.7UF 10V X5R 0603
U4: XC7A100T-FGG484; Xilinx_FGG484; Part Description IC FPGA 285 I/O 484FBGA

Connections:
/Connectors/3V3_FD: C57.1, C58.1; also elsewhere on the board
/Main Power/1V0_FD: C43.1, C44.2, C45.2, C46.2, C47.2, C52.1, C53.2, C54.2, C55.2, C56.2, U4.E12 (VCCBATT_0), U4.H8 (VCCINT), U4.H10 (VCCINT), U4.J7 (VCCINT), U4.J9 (VCCINT), U4.J11 (VCCBRAM), U4.K8 (VCCINT), U4.L7 (VCCINT), U4.L11 (VCCBRAM), U4.M8 (VCCINT), U4.N7 (VCCINT), U4.N11 (VCCBRAM), U4.P8 (VCCINT), U4.P10 (VCCINT), U4.R7 (VCCINT), U4.R9 (VCCINT), U4.T8 (VCCINT), U4.T10 (VCCINT); also elsewhere on the board
/Main Power/1V0_MGT: C48.1, C49.1; also elsewhere on the board
/Main Power/1V2_MGT: C50.1, C51.1; also elsewhere on the board
/Main Power/1V8_FD: C61.1, C62.1, C63.2, C64.2, C65.2, U4.H12 (VCCAUX), U4.K10 (VCCADC_0), U4.K12 (VCCAUX), U4.M12 (VCCAUX), U4.P12 (VCCAUX), U4.R11 (VCCAUX); also elsewhere on the board
/Main Power/1V35_DDR: C59.1, C60.1; also elsewhere on the board

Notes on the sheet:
Power sequencing: 1. VCCINT, VCCBRAM, MGTAVCC 2. VCCAUX 3. MGTAVTT 4. VCCO

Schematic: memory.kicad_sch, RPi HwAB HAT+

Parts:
C69, C71, C72, C73, C74: 0.1uF; C_0402_1005Metric; Part Description CAP CER 0.1UF 16V X7R 0402
C70: 4.7uF; C_0603_1608Metric; Part Description CAP CER 4.7UF 10V X5R 0603
R20: 240 1%; R_0402_1005Metric; Part Description RES 240 OHM 1% 1/16W 0402
R31, R32: 2.2K 1%; R_0402_1005Metric; Part Description RES 2.2K OHM 1% 1/16W 0402
U6: MT41K256M16TW-107:P TR; Micron_FBGA-96_7.5x13.5mm_Layout9x16_P0.8mm; Part Description IC DRAM 4GBIT PAR 96FBGA
U7: MX25L12835F; WSON-8-1EP_6x5mm_P1.27mm_EP3.4x4mm; Part Description IC FLASH 128MBIT SPI 8WSON

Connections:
/Connectors/3V3_FD: C74.2, U7.8 (VCC); also elsewhere on the board
/Connectors/QSPI0.CS0n: U7.1 (~CS); also elsewhere on the board
/Connectors/QSPI0.SCLK: U7.6 (SCLK); also elsewhere on the board
/Connectors/QSPI0.SIO0: U7.5 (SI/SIO0); also elsewhere on the board
/Connectors/QSPI0.SIO1: U7.2 (SO/SIO1); also elsewhere on the board
/Connectors/QSPI0.SIO2: U7.3 (~WP/SIO2); also elsewhere on the board
/Connectors/QSPI0.SIO3: U7.7 (~HOLD/SIO3); also elsewhere on the board
/FPGA/FPGA 34, 35/A0: U6.N3 (A0); also elsewhere on the board
/FPGA/FPGA 34, 35/A1: U6.P7 (A1); also elsewhere on the board
/FPGA/FPGA 34, 35/A2: U6.P3 (A2); also elsewhere on the board
/FPGA/FPGA 34, 35/A3: U6.N2 (A3); also elsewhere on the board
/FPGA/FPGA 34, 35/A4: U6.P8 (A4); also elsewhere on the board
/FPGA/FPGA 34, 35/A5: U6.P2 (A5); also elsewhere on the board
/FPGA/FPGA 34, 35/A6: U6.R8 (A6); also elsewhere on the board
/FPGA/FPGA 34, 35/A7: U6.R2 (A7); also elsewhere on the board
/FPGA/FPGA 34, 35/A8: U6.T8 (A8); also elsewhere on the board
/FPGA/FPGA 34, 35/A9: U6.R3 (A9); also elsewhere on the board
/FPGA/FPGA 34, 35/A10: U6.L7 (A10/AP); also elsewhere on the board
/FPGA/FPGA 34, 35/A11: U6.R7 (A11); also elsewhere on the board
/FPGA/FPGA 34, 35/A12: U6.N7 (A12/~BC); also elsewhere on the board
/FPGA/FPGA 34, 35/A13: U6.T3 (A13); also elsewhere on the board
/FPGA/FPGA 34, 35/A14: U6.T7 (A14); also elsewhere on the board
/FPGA/FPGA 34, 35/DDR_BA0: U6.M2 (BA0); also elsewhere on the board
/FPGA/FPGA 34, 35/DDR_BA1: U6.N8 (BA1); also elsewhere on the board
/FPGA/FPGA 34, 35/DDR_BA2: U6.M3 (BA2); also elsewhere on the board
/FPGA/FPGA 34, 35/DDR_CASn: U6.K3 (~CAS); also elsewhere on the board
/FPGA/FPGA 34, 35/DDR_CKE: U6.K9 (CKE); also elsewhere on the board
/FPGA/FPGA 34, 35/DDR_CK_N: U6.K7 (~CK); also elsewhere on the board
/FPGA/FPGA 34, 35/DDR_CK_P: U6.J7 (CK); also elsewhere on the board
/FPGA/FPGA 34, 35/DDR_CSn: U6.L2 (~CS); also elsewhere on the board
/FPGA/FPGA 34, 35/DDR_LDM: U6.E7 (LDM); also elsewhere on the board
/FPGA/FPGA 34, 35/DDR_LDQS_N: U6.G3 (~LDQS); also elsewhere on the board
/FPGA/FPGA 34, 35/DDR_LDQS_P: U6.F3 (LDQS); also elsewhere on the board
/FPGA/FPGA 34, 35/DDR_ODT: U6.K1 (ODT); also elsewhere on the board
/FPGA/FPGA 34, 35/DDR_RASn: U6.J3 (~RAS); also elsewhere on the board
/FPGA/FPGA 34, 35/DDR_RESETn: U6.T2 (~RESET); also elsewhere on the board
/FPGA/FPGA 34, 35/DDR_UDM: U6.D3 (UDM); also elsewhere on the board
/FPGA/FPGA 34, 35/DDR_UDQS_N: U6.B7 (~UDQS); also elsewhere on the board
/FPGA/FPGA 34, 35/DDR_UDQS_P: U6.C7 (UDQS); also elsewhere on the board
/FPGA/FPGA 34, 35/DDR_WEn: U6.L3 (~WE); also elsewhere on the board
/FPGA/FPGA 34, 35/DQ0: U6.E3 (DQ0); also elsewhere on the board
/FPGA/FPGA 34, 35/DQ1: U6.F7 (DQ1); also elsewhere on the board
/FPGA/FPGA 34, 35/DQ2: U6.F2 (DQ2); also elsewhere on the board
/FPGA/FPGA 34, 35/DQ3: U6.F8 (DQ3); also elsewhere on the board
/FPGA/FPGA 34, 35/DQ4: U6.H3 (DQ4); also elsewhere on the board
/FPGA/FPGA 34, 35/DQ5: U6.H8 (DQ5); also elsewhere on the board
/FPGA/FPGA 34, 35/DQ6: U6.G2 (DQ6); also elsewhere on the board
/FPGA/FPGA 34, 35/DQ7: U6.H7 (DQ7); also elsewhere on the board
/FPGA/FPGA 34, 35/DQ8: U6.D7 (DQ8); also elsewhere on the board
/FPGA/FPGA 34, 35/DQ9: U6.C3 (DQ9); also elsewhere on the board
/FPGA/FPGA 34, 35/DQ10: U6.C8 (DQ10); also elsewhere on the board
/FPGA/FPGA 34, 35/DQ11: U6.C2 (DQ11); also elsewhere on the board
/FPGA/FPGA 34, 35/DQ12: U6.A7 (DQ12); also elsewhere on the board
/FPGA/FPGA 34, 35/DQ13: U6.A2 (DQ13); also elsewhere on the board
/FPGA/FPGA 34, 35/DQ14: U6.B8 (DQ14); also elsewhere on the board
/FPGA/FPGA 34, 35/DQ15: U6.A3 (DQ15); also elsewhere on the board
/Main Power/1V35_DDR: C71.2, C72.2, C73.2, R20.2, R31.1, U6.A1 (V_{DDQ}), U6.A8 (V_{DDQ}), U6.B2 (V_{DD}), U6.C1 (V_{DDQ}), U6.C9 (V_{DDQ}), U6.D2 (V_{DDQ}), U6.D9 (V_{DD}), U6.E9 (V_{DDQ}), U6.F1 (V_{DDQ}), U6.G7 (V_{DD}), U6.H2 (V_{DDQ}), U6.H9 (V_{DDQ}), U6.K2 (V_{DD}), U6.K8 (V_{DD}), U6.N1 (V_{DD}), U6.N9 (V_{DD}), U6.R1 (V_{DD}), U6.R9 (V_{DD}); also elsewhere on the board
unnamed: C69.2, C70.1, R31.2, R32.1, U6.H1 (V_{REFDQ}), U6.M8 (V_{REFCA})
unnamed: R20.1, U6.L8 (ZQ)

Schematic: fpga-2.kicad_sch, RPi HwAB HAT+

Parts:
C22, C23, C24, C25, C26, C27: 0.1uF; C_0402_1005Metric; Part Description CAP CER 0.1UF 16V X7R 0402
U4: XC7A100T-FGG484; Xilinx_FGG484; Part Description IC FPGA 285 I/O 484FBGA

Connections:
/Connectors/3V3_FD: C22.2, C23.2, C24.2, C25.2, C26.2, C27.2, U4.A17 (VCCO_16), U4.B14 (VCCO_16), U4.C21 (VCCO_16), U4.D18 (VCCO_16), U4.E15 (VCCO_16), U4.F22 (VCCO_16), U4.G19 (VCCO_15), U4.H16 (VCCO_15), U4.J13 (VCCO_15), U4.K20 (VCCO_15), U4.L17 (VCCO_15), U4.N21 (VCCO_15); also elsewhere on the board

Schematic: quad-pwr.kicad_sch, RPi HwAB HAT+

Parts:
C7, C8, C9, C10, C11: 2.2uF; C_0603_1608Metric; Part Description CAP CER 2.2UF 25V X5R 0603
C12, C13, C14, C15: 22uF; C_0603_1608Metric; Part Description CAP CER 22UF 10V X5R 0603
L1, L2, L3, L4: 1.5uH; L_Coilcraft_XAL4020-XXX; Part Description FIXED IND 1.5UH 7.5A 23.6MOHM SM
R12, R13, R14, R15: 22K; R_0402_1005Metric; Part Description RES 22K OHM 1% 1/16W 0402
U3: MAX20029; WQFN-28-1EP_4x4mm_P0.4mm_EP2.7x2.7mm; Part Description IC REG BUCK ADJ 1.5A QUAD 28TQFN

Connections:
/Connectors/3V3_FD: C13.1, L3.2, U3.14 (OUTS3); also elsewhere on the board
/Main Power/1V0/1V0_PG: U3.1 (EN1); also elsewhere on the board
/Main Power/1V2_MGT: C12.1, L4.2, U3.22 (OUTS4); also elsewhere on the board
/Main Power/1V8_FD: C15.1, L1.2, U3.28 (OUTS1); also elsewhere on the board
/Main Power/1V35_DDR: C14.1, L2.2, U3.8 (OUTS2); also elsewhere on the board
/Main Power/3V3_PG: R13.1, U3.12 (PG3); also elsewhere on the board
/Main Power/5V0_N: C7.1, C8.1, C9.1, C10.1, C11.1, R12.2, R13.2, R14.2, R15.2, U3.2 (PV1), U3.7 (PV2), U3.15 (PV3), U3.20 (PV4), U3.26 (VA); also elsewhere on the board
/Main Power/Quad Buck/1V2_PG: R12.1, U3.9 (EN2), U3.13 (EN3), U3.23 (PG4)
/Main Power/Quad Buck/1V8_PG: R15.1, U3.21 (EN4), U3.27 (PG1)
/Main Power/Quad Buck/1V35_PG: R14.1, U3.10 (PG2)
/Main Power/Quad Buck/LX1: L1.1, U3.3 (LX1)
/Main Power/Quad Buck/LX2: L2.1, U3.6 (LX2)
/Main Power/Quad Buck/LX3: L3.1, U3.16 (LX3)
/Main Power/Quad Buck/LX4: L4.1, U3.19 (LX4)

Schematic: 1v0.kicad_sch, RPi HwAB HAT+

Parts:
C3: 22uF; C_0603_1608Metric; Part Description CAP CER 22UF 10V X5R 0603
C4: 0.1uF; C_0402_1005Metric; Part Description CAP CER 0.1UF 16V X7R 0402
C5: 10uF; C_1206_3216Metric; Part Description CAP TANT 10UF 20% 10V 1206
C6: 4.7nF; C_0402_1005Metric; Part Description CAP CER 0402 4.7NF 50V X7R 5%
FB1: 120R @ 100MHz; L_0603_1608Metric; Part Description FERRITE BEAD 120 OHM 0603 1LN
R6: 0.005; R_1206_3216Metric; Part Description RES 0.005 OHM 1% 1W 1206
R7: 10K 1%; R_0402_1005Metric; Part Description RES 10K OHM 1% 1/16W 0402
R8, R9: 10; R_0402_1005Metric; Part Description RES 10 OHM 1% 1/16W 0402
R10: 15K 1%; R_0402_1005Metric; Part Description RES 15K OHM 1% 1/16W 0402
R11: 22K; R_0402_1005Metric; Part Description RES 22K OHM 1% 1/16W 0402
U2: TPSM82903; TPSM82903SISR; Part Description 3-V TO 17-V, 3-A, HIGH-EFFICIENC

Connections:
/Connectors/PCIE.PWR_EN: U2.3 (EN); also elsewhere on the board
/Main Power/1V0/1V0_FB: R7.2, R10.1, U2.7 (FB/VSET)
/Main Power/1V0/1V0_P: C3.1, R6.2, R7.1, R8.2, U2.9 (VOUT), U2.10 (VOUT)
/Main Power/1V0/1V0_PG: R11.1, U2.6 (PG); also elsewhere on the board
/Main Power/1V0_FD: FB1.1, R6.1, R9.2; also elsewhere on the board
/Main Power/1V0_MGT: FB1.2; also elsewhere on the board
/Main Power/1V0_SENS_N: C4.1, R8.1; also elsewhere on the board
/Main Power/1V0_SENS_P: C4.2, R9.1; also elsewhere on the board
/Main Power/5V0_N: C5.1, R11.2, U2.1 (VIN), U2.2 (VIN), U2.4 (MODE); also elsewhere on the board
unnamed: C6.1, U2.5 (SS/TR)

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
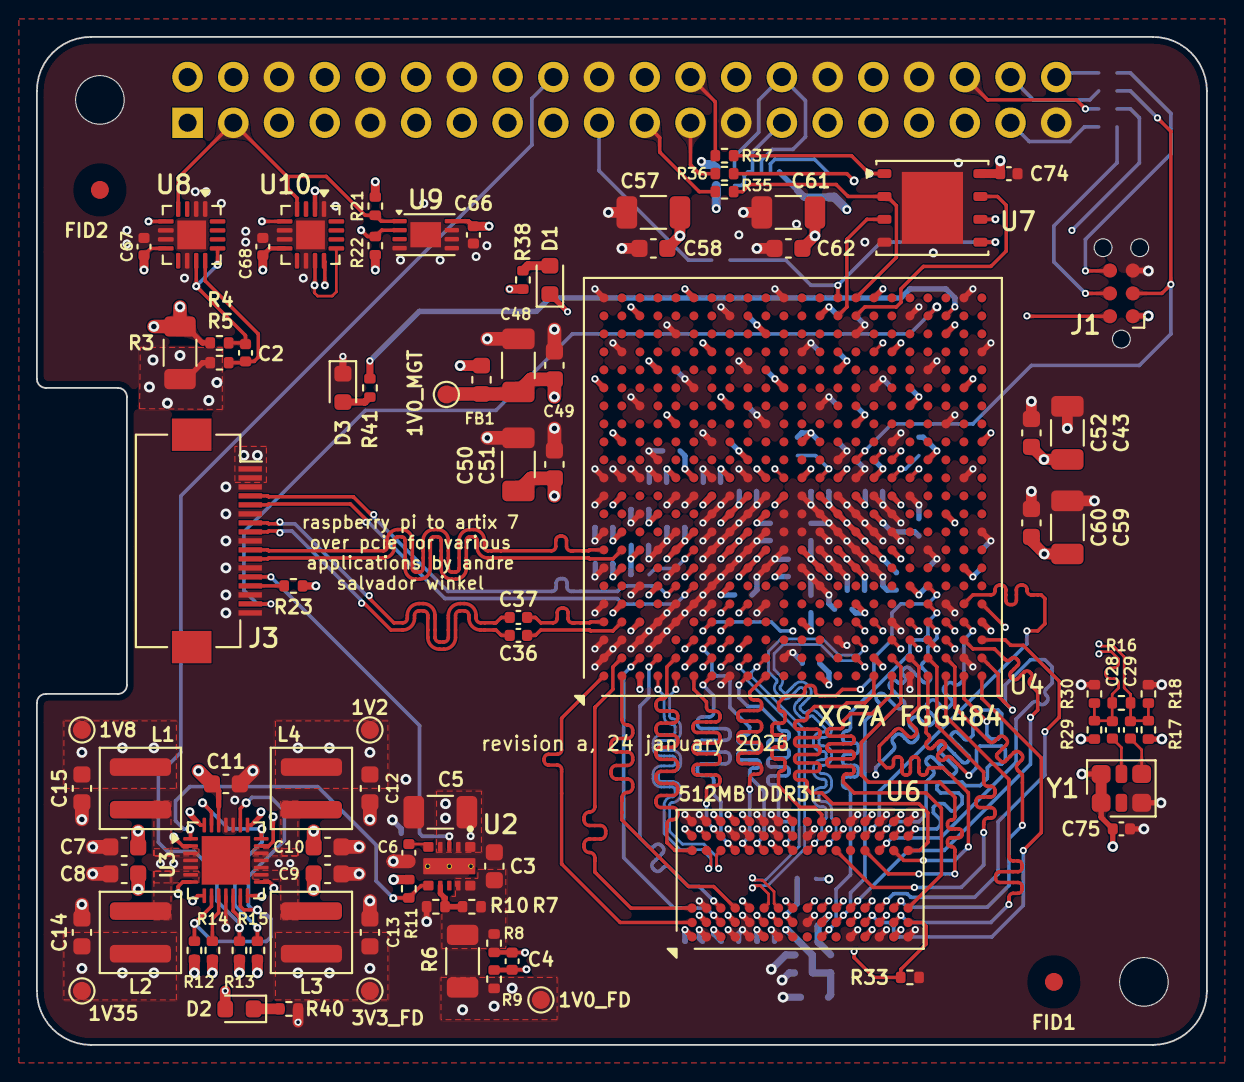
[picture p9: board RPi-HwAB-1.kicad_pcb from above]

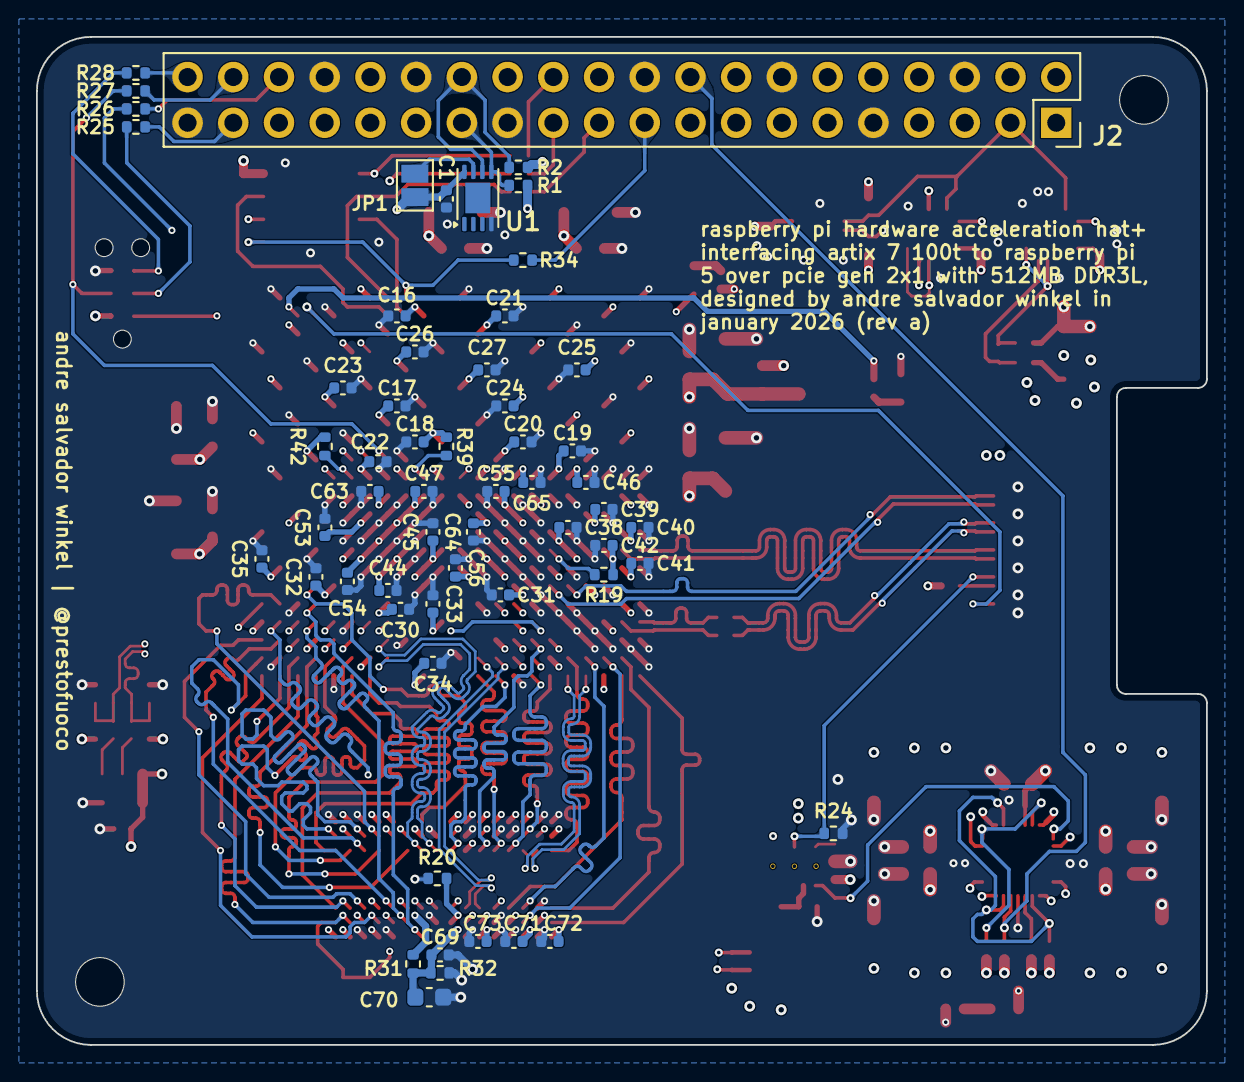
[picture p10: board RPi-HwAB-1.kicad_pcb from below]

Board: 8 copper layers, 65.0 x 56.0 mm, 149 parts (57 on the bottom side), 123 nets.

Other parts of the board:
1V0_FD, 1V0_MGT, 1V2, 1V8, 1V35, 3V3_FD: TestPoint; TestPoint_Pad_D1.0mm
MH1, MH4: MountingHole_2.7mm_M2.5

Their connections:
/Connectors/3V3_FD: 3V3_FD.1 (1_1); also elsewhere on the board
/Main Power/1V0_FD: 1V0_FD.1 (1_1); also elsewhere on the board
/Main Power/1V0_MGT: 1V0_MGT.1 (1_1); also elsewhere on the board
/Main Power/1V2_MGT: 1V2.1 (1_1); also elsewhere on the board
/Main Power/1V8_FD: 1V8.1 (1_1); also elsewhere on the board
/Main Power/1V35_DDR: 1V35.1 (1_1); also elsewhere on the board

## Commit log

2025-08-23 file restructuring
    redefined naming scheme for schematic files (fpga-num) etc.
    [RPi-HwAB-1.kicad_sch, fpga-14.kicad_sch, fpga-15.kicad_sch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]
2025-08-23 restructure project
    [RPi-HwAB-1.kicad_pcb, RPi-HwAB-1.kicad_sch, fpga-1.kicad_sch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]
2025-08-23 Correct 'kicad/altium' to 'kicad' in README
2025-08-23 current sense, fpga power sequencing
    plus restructuring files
    [RPi-HwAB-1.kicad_sch, fpga-3.kicad_sch, fpga-pwr.kicad_sch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]
2025-08-23 add sensors, hierarchical changes
    [RPi-HwAB-1.kicad_sch, debug.kicad_sch, fpga-1.kicad_sch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]
2025-08-23 addl. updates to power hierarchy
    [RPi-HwAB-1.kicad_pcb, RPi-HwAB-1.kicad_sch, debug.kicad_sch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]
2025-08-24 added power sequencing through raspi gpio
    additionally defined sensors
    [RPi-HwAB-1.kicad_sch, debug.kicad_sch, fpga-1.kicad_sch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]
2025-08-24 Fix typo and update wording in README.md
    Corrected a typo in the hardware section and adjusted wording in the PCB design section.
2025-08-24 quick edits to hierarchy
    [RPi-HwAB-1.kicad_pcb, RPi-HwAB-1.kicad_sch, fpga-3.kicad_sch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]
2025-08-24 added power supply simulations
    [RPi-HwAB-1.kicad_sch, fpga-1.kicad_sch, sensors.kicad_sch]
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2025-08-24 Replace schematic image with updated version
    Updated the schematic image in the README.
2025-08-25 defined pcie diff. connections
    [RPi-HwAB-1.kicad_sch, decoupling.kicad_sch, fpga-3.kicad_sch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]
2025-08-25 removed redundant sheet
    [debug.kicad_sch]
2025-08-25 connected jtag-fpga, tc2030
    [RPi-HwAB-1.kicad_sch, fpga-1.kicad_sch]
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2025-08-29 reorg hierarchical, define buses
    added bus definitions, aliasing, reorganized sub-sheets for hierarchical interpretation, grouped fpga. pending dram and mram addition
    [RPi-HwAB-1.kicad_sch, connectors.kicad_sch, fpga-1.kicad_sch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]
2025-08-29 fixed page numbering
    per previous commit
    [RPi-HwAB-1.kicad_sch, fpga-pwr.kicad_sch, fpga.kicad_sch]
2025-08-30 completed bus aliasing definitions
    [RPi-HwAB-1.kicad_sch, connectors.kicad_sch, fpga-1.kicad_sch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]
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2025-08-30 updated sims, power hierarchy
    added power flags to voltage buses, removed standard kicad "+3.3V" power flags and using standard kicad "power flag" in order to use hierarchical labels to visually show power paths
    [RPi-HwAB-1.kicad_sch, connectors.kicad_sch, fpga-pwr.kicad_sch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]
2025-08-30 updated power hierarchy and sims
    [main-pwr.kicad_sch]
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2025-09-03 edits to simulations
    [main-pwr.kicad_sch]
2025-09-03 power supply template~?
    [main-pwr.kicad_sch]
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2025-09-16 buck outputs
    [main-pwr.kicad_sch]
2025-09-17 restructured power hierarchy
    [RPi-HwAB-1.kicad_sch, fpga-pwr.kicad_sch, fpga.kicad_sch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]
2025-09-17 power supply comp abstraction
    [RPi-HwAB-1.kicad_sch, compensation.kicad_sch, fpga-pwr.kicad_sch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]
2025-09-17 hierarchical current sense
    [RPi-HwAB-1.kicad_sch, connectors.kicad_sch, fpga.kicad_sch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]
2025-09-17 Fix formatting of schematic hierarchy in README
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2025-09-19 current sense hierarchy definition
    [RPi-HwAB-1.kicad_sch, fpga-1.kicad_sch, fpga-2.kicad_sch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]
2025-09-19 power flags
    [RPi-HwAB-1.kicad_sch, connectors.kicad_sch, fpga-pwr.kicad_sch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]
2025-09-19 changed spi flash to wson
    [RPi-HwAB-1.kicad_pcb, compensation.kicad_sch, decoupling.kicad_sch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]
2025-09-21 removed one I-sense
    [sensors.kicad_sch]
2025-09-21 fpga decoupling
    [RPi-HwAB-1.kicad_sch, decoupling.kicad_sch, fpga-pwr.kicad_sch]
2025-09-21 pcie definitions
    [RPi-HwAB-1.kicad_pcb, RPi-HwAB-1.kicad_sch, connectors.kicad_sch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]
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2025-09-26 added dram, defined pcie sideband sigs.
    [RPi-HwAB-1.kicad_sch, connectors.kicad_sch, fpga-1.kicad_sch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]
2025-10-15 added potential power sequencer
    [RPi-HwAB-1.kicad_sch, main-pwr.kicad_sch]
2025-11-03 saved libraries to project
    [RPi-HwAB-1.kicad_sch, compensation.kicad_sch, connectors.kicad_sch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]
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2025-11-04 hierarchy and power sequencing, level shift
    [RPi-HwAB-1.kicad_sch, connectors.kicad_sch, fpga.kicad_sch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]
2025-11-04 added hierarchical sheet, pwr seq
    [RPi-HwAB-1.kicad_sch, fpga.kicad_sch, main-pwr.kicad_sch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]
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2026-01-03 changes to power tree
    [1v0.kicad_sch, 1v2.kicad_sch, 1v35.kicad_sch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]
2026-01-03 moved stuff around, bom
    [1v0.kicad_sch, 1v2.kicad_sch, 1v35.kicad_sch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]
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2026-01-05 power cleanup, pdf sch
    [fpga-pwr.kicad_sch, fpga.kicad_sch]
2026-01-05 quick fix top-level sch
    [RPi-HwAB-1.kicad_sch]
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2026-01-06 initial layout, dogbone fanout
    [3v3.kicad_sch, RPi-HwAB-1.kicad_pcb]
2026-01-07 added mig ddr pinout constraints
    [1v0.kicad_sch, 1v35.kicad_sch, 1v8.kicad_sch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]
2026-01-08 real ddr pinout done
    [RPi-HwAB-1.kicad_pcb, fpga-1.kicad_sch, fpga-3.kicad_sch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]
2026-01-10 restructured power, power plane layout
    [1v0.kicad_sch, 1v2.kicad_sch, 1v35.kicad_sch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]
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2026-01-14 change to 8 layers, impedance calc, ddr routing
    [RPi-HwAB-1.kicad_pcb, memory.kicad_sch, sensors.kicad_sch]
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2026-01-15 length matched ddr upper and lower data bytes, pending address
    [RPi-HwAB-1.kicad_pcb, fpga-3.kicad_sch]
2026-01-15 power plane apportionment redid power planes, clearance to 0.2mm, most on l5, some on l6
    [RPi-HwAB-1.kicad_pcb]
2026-01-24 ported to nightly, finished ddr routing yay!!!!!!! pcb/v1.0 almost complete!
    [1v0.kicad_sch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]
2026-01-24 routing done! pcb/v1.0 almost ready for release added series resistors from raspi spi to qspi, all nets connected and routed
    [RPi-HwAB-1.kicad_pcb, connectors.kicad_sch, fpga-1.kicad_sch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]
2026-01-24 quick fix pcie length matching w/ better nightly build previous rev kicad (current rel?) was being bad for length matching through layers, or something like that. just adjusted skew for pcie 2x1 trac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
    [RPi-HwAB-1.kicad_pcb]
2026-01-24 complete! added and prettied up silkscreen
    [RPi-HwAB-1.kicad_pcb, connectors.kicad_sch, fpga-1.kicad_sch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]
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2026-01-24 added slksc and sldrmsk
    [RPi-HwAB-1.kicad_pcb]
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2026-01-27 remove readme, add jlc [skip ci]
    [jlcbom.xls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]
